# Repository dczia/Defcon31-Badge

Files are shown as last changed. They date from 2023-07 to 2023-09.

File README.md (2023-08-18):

# Defcon31-Badge
DCZia 2023 DC31 Badge - Electric Sampler

```
   ____  ___________   _          ________          __       _
   / __ \/ ____/__  /  (_)___ _   / ____/ /__  _____/ /______(_)____
  / / / / /      / /  / / __ `/  / __/ / / _ \/ ___/ __/ ___/ / ___/
 / /_/ / /___   / /__/ / /_/ /  / /___/ /  __/ /__/ /_/ /  / / /__
/_____/\____/  /____/_/\__,_/  /_____/_/\___/\___/\__/_/  /_/\___/

   _____                       __
  / ___/____ _____ ___  ____  / /__  _____
  \__ \/ __ `/ __ `__ \/ __ \/ / _ \/ ___/
 ___/ / /_/ / / / / / / /_/ / /  __/ /
/____/\__,_/_/ /_/ /_/ .___/_/\___/_/
                    /_/
```

## About
The DCZia Electric Sampler - A eurorack format drum machine, sampler, and step sequencer powered by
the Pi2040.

## Specs

RPI 2040 Microconroller
OLED Screen
3.5mm Audio Out Jack
3.5mm Midi In / Out (TRRS)
3.5mm Sync In / Out
MicroSD Card Slot
Eurorack Power Connector
Battery Power

## Build Guide

The badge comes with all surface mount components already assembled on the board. You will need to
solder on the keyswitches, audio jacks, screen, rotary encoders, and battery box.

First add the audio jacks. Install all the jacks and make sure they are flat and perpendicular with
the board. Next install the front board first aligning the jacks with the holes in the front board.
Then connect the bottom pin header to the front board. The header will be off by one, THIS IS OK for
the v1.1 board! Then carefully flip over the board and solder on the jacks.

Remove the front panel.

Then insert a keyswitch, or all keyswitches onto the board. Check that the metal pins are not bent,
and if so gently straignten them out with your fingers or a pair of tweezers. Carfully flip the
board over and solder on the keyswitches.

Next add the rotary encoders. Push them through the board, and you may need to gently fold in the
side stabilization pins if they do not line up correctly. Flip over the board and solder these in. 

Next with the board facing forward and on a flat surface, put the screen in. The legs of the screen
should not protrude through the back of the board past the holes, or only a tiny bit. You may need
to use something like a pencil or something to help the screen lay flat, standing off from the
board. Gently solder from the front to establish a mechanical connection to the board, then once the
screen is secure, flip over and solder the back. You must solder the back pads to endure a
connection from the screen to the microcrontroller. 

Finally flip the board over and gently attach the battery pack somewhere on the back with the
supplied double sticky tape. Then solder on the leads from the battery pack to the pads on the
bottom left side of the back of the board.

## User Manual

Currently the firmware is not complete, and the user interface may change.

The Select Knob will change between options on the screen, and push selects the currently
highlighted option.

The Volume knob will change the volume.

The PLAY button will play / pause any currently running program

There are a few modes on the v1 software.
A LED light mode.
A Sampler mode with a sequencer. You can load a wav file from the onboard flash, and then add a sequence and control the steps with the 8 key switches, and adjust per step volume.
A Sequencer mode which will play pre progarmed sequences. (Still under dev)
A Midi controller mode. You can adjust what notes / cc params are output via the python code in our repo.
A USB HID Device mode. The keys will output 0-9 and the device will emulate a keyboard.

## Notes

If you picked up a V1 board at Con, the board shipped with our testing firmware. Please flash the V1 firmware for more features.

Additional Features and changes will be coming soon!

## Updating the software / firmware

To update the software on the board you can do two things.

1. Use the fimware blob from our release section. To use this, unplug and turn off the module. Using something non conductivem press and hold the button on the RPI 2040 (The BootSelect Button) while powering on the unit via a micro usb cable. You should then see a mass storage drive appear on your computer. Drag the single uf2 file onto the drive. Then the unit should restart with the new firmware.

2. You can also plug the unit into your computer via the micro usb and drag the contents of the Production/Software folder onto the mass storage drive. The unit should reboot when complete. Sometimes if your computer transfers the files too slow this can cause issues with the RPI rebooting before all the software is complete.

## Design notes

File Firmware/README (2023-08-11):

To flash, hold down the BOOTSEL button on the Pi Pico and plug into a computer
Copy the DCZiaSampler.uf2 to the Pico
The Pico should automatically reboot with the full firmware

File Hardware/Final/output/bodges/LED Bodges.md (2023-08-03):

### Bodges required for 1.0 LED board

These bodges are required in order for a version 1.0 LED board (no version note on the board) to work with a 1.0 or 1.1 back board.  If you have a later version of the LED board, you will not need these changes and you will have to revert your backboard.

### The Issue

When designing the board to board connector, originally a 4 pin connector was used.  The master layout was created, and then forked into the front board and the back board.  Later, there was a desire to bring SDA/SCL to the front board for the SAO connector, so the board-to-board was updated to be a 5 pin.

However, on the front board the new pin was added to the bottom, and on the back board the new pin was added to the top, leaving us with a off-by-one error

### The Fix

To fix this, we will sever the I2C SDA/SCL lines, and move the power lines slightly.  You will need a sharp knife to cut the traces and also to remove some solder mask, some rosin flux solder, and a short piece of wire.

Start with the front board.  Locate the board to board connector at the lower left of the board.

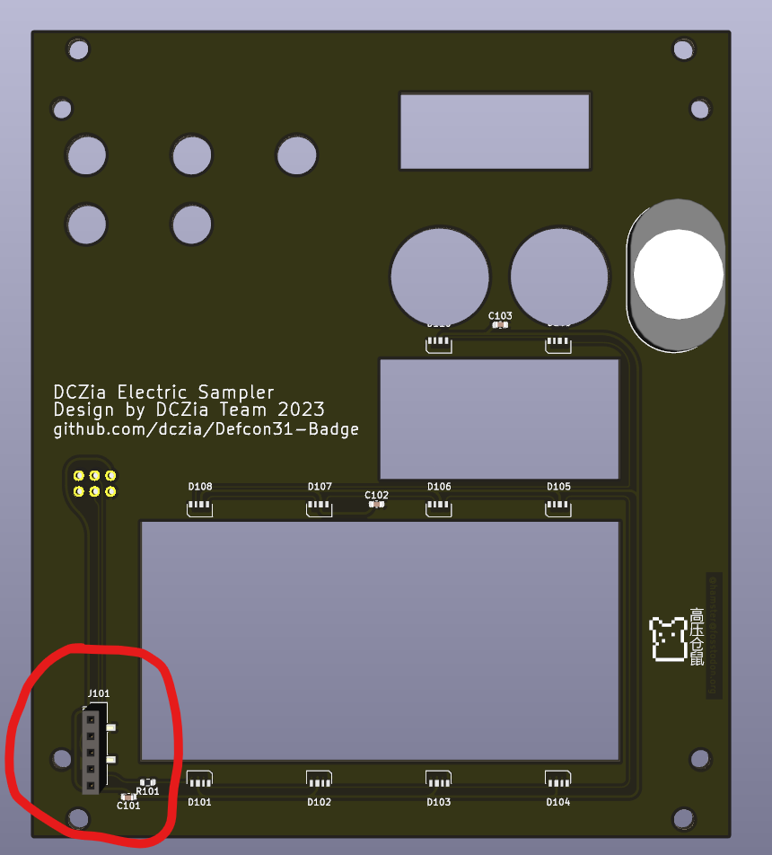
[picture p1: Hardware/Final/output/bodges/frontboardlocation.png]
front


1. Take your knife and sever the two I2C lines above the connector.  These are the thin ones to the right - ***DO NOT*** cut the thicker line to the left.  
2. Take a short piece of wire, and jumper pin 4 of the connector to the left terminal of R101.

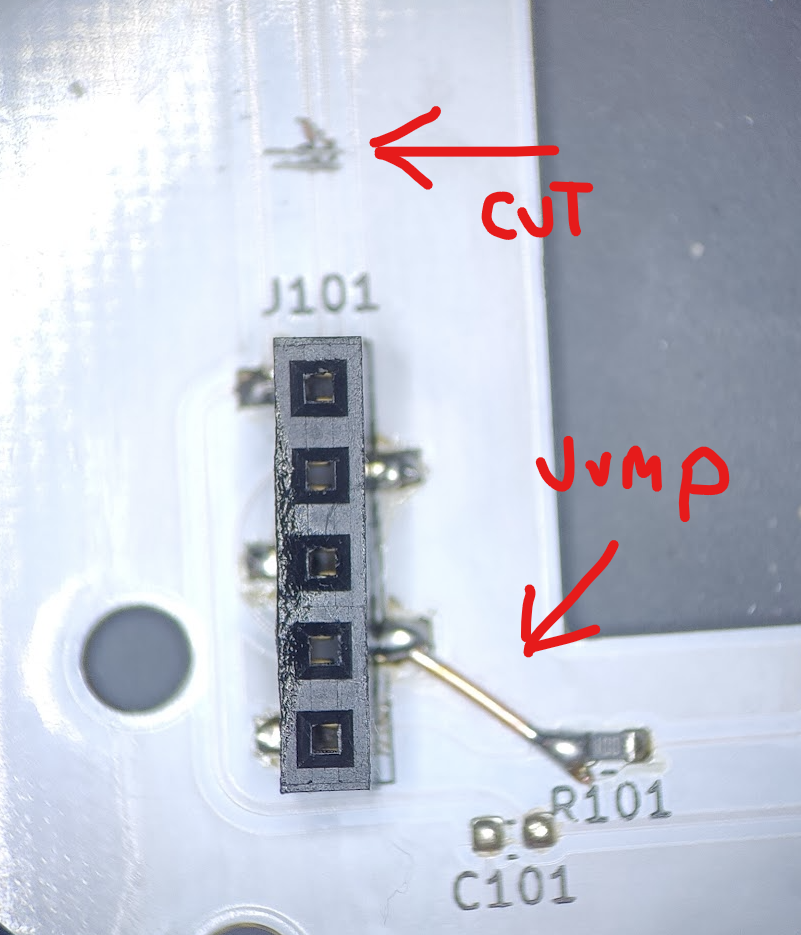
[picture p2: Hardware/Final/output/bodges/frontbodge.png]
frontbodge


Now we will move the back board.  Flip the board over to see the back side.  Locate the 5 pin connector in the lower left of the board.

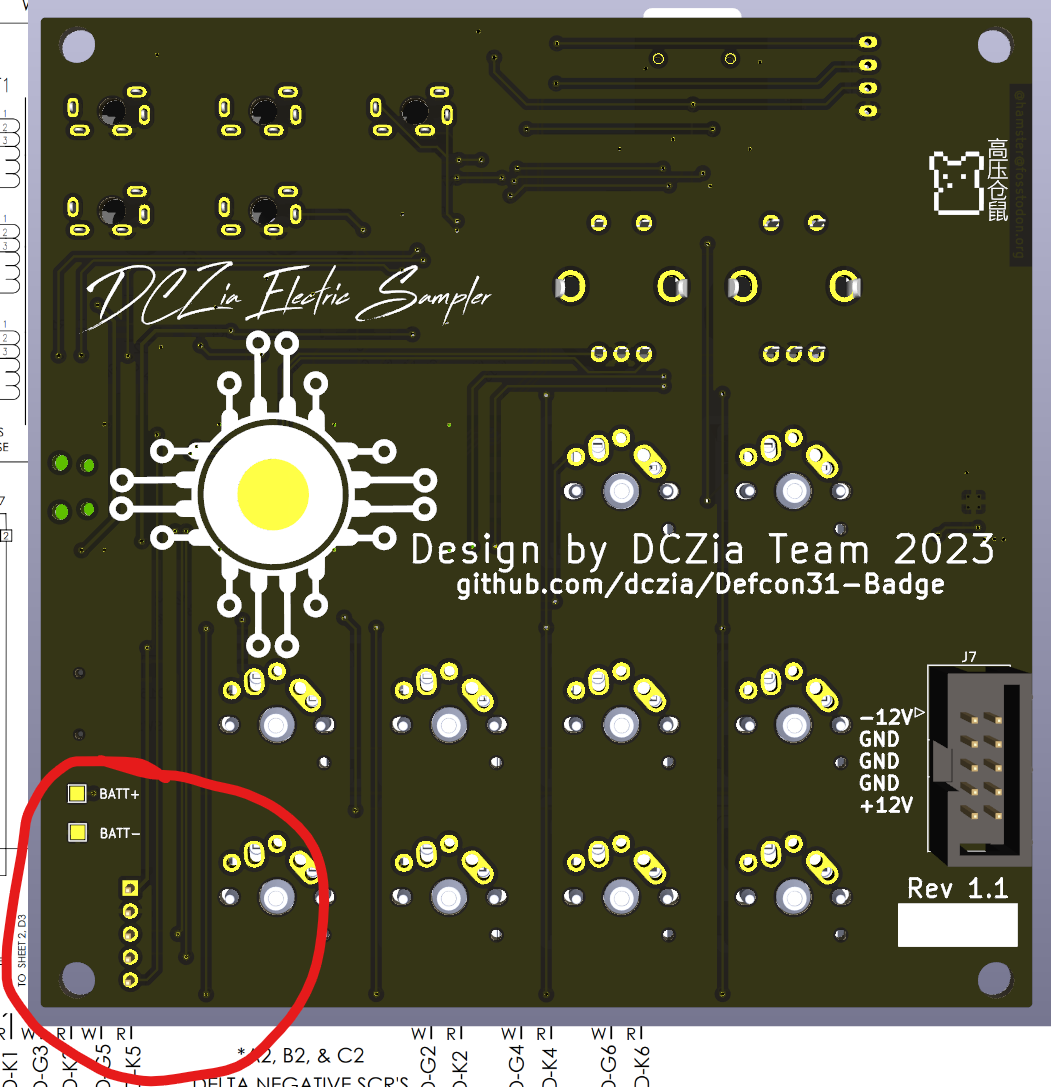
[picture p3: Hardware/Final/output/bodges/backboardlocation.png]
back


At this location, you will need to perform several actions.

1. Using solder, bridge the top two pins together.  Heat both, apply solder, and continue applying solder while pulling the iron away.
2. The second pin here is connected to the ground plane via a single trace.  Sever this trace.
3. At pin 3, scrape some of the solder mask off the ground plane next to it.  Using your solder, tin the exposed copper, and then using the technique from (1) bridge the ground plane with pin 3.
4. Locate the I2C lines to the right of the connector.  These are the small lines that both go into vias at the bottom.  Sever these lines with your knife.

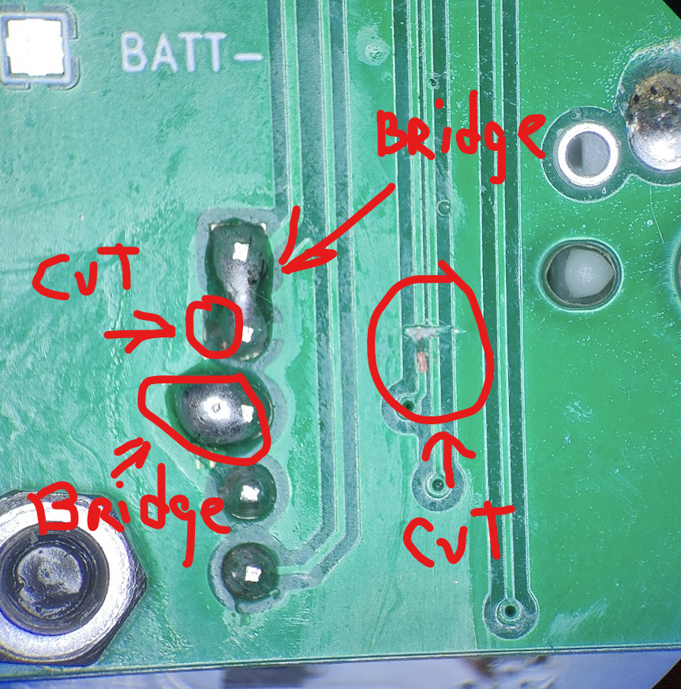
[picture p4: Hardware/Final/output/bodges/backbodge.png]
backbodge


At this point, the LEDs will now work.

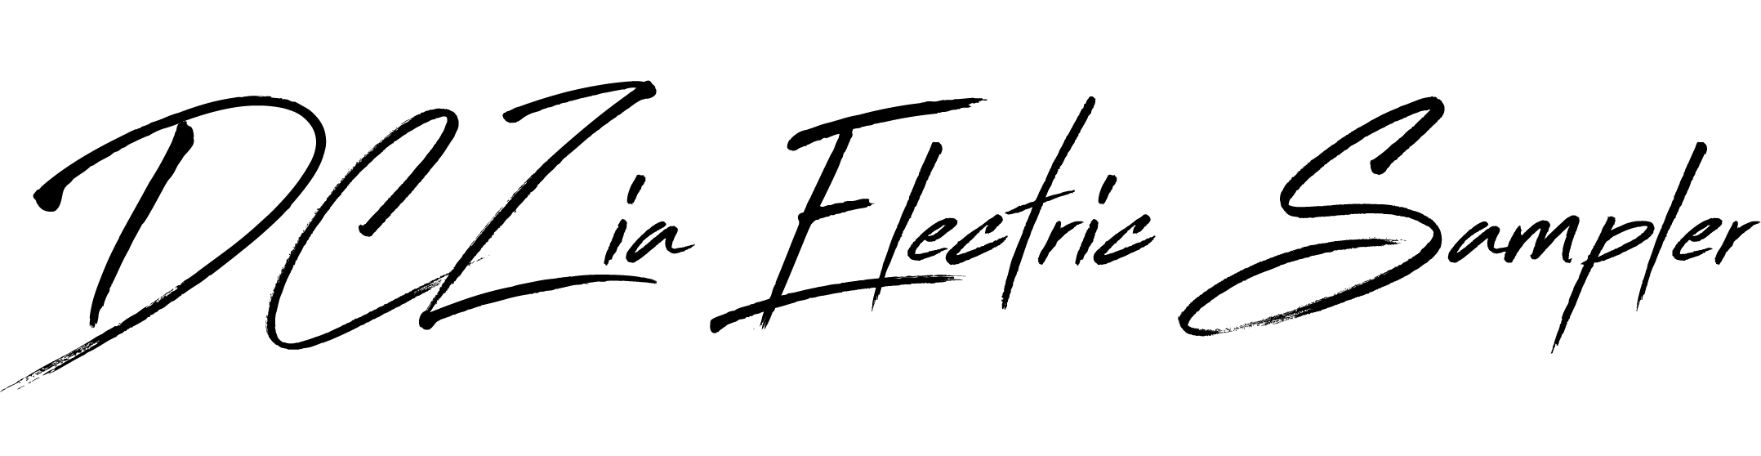
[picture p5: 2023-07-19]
Hardware/Final/images/DCZiaElectricSampler.png

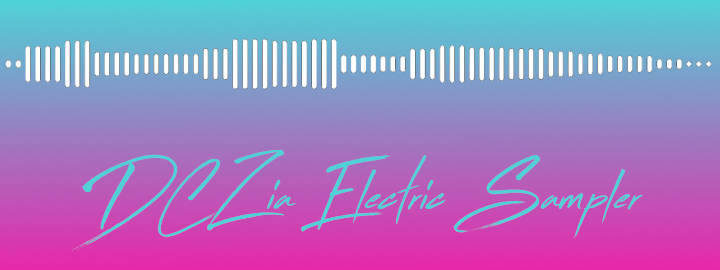
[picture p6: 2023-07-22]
Images/dc31-ziastickerlarge.png

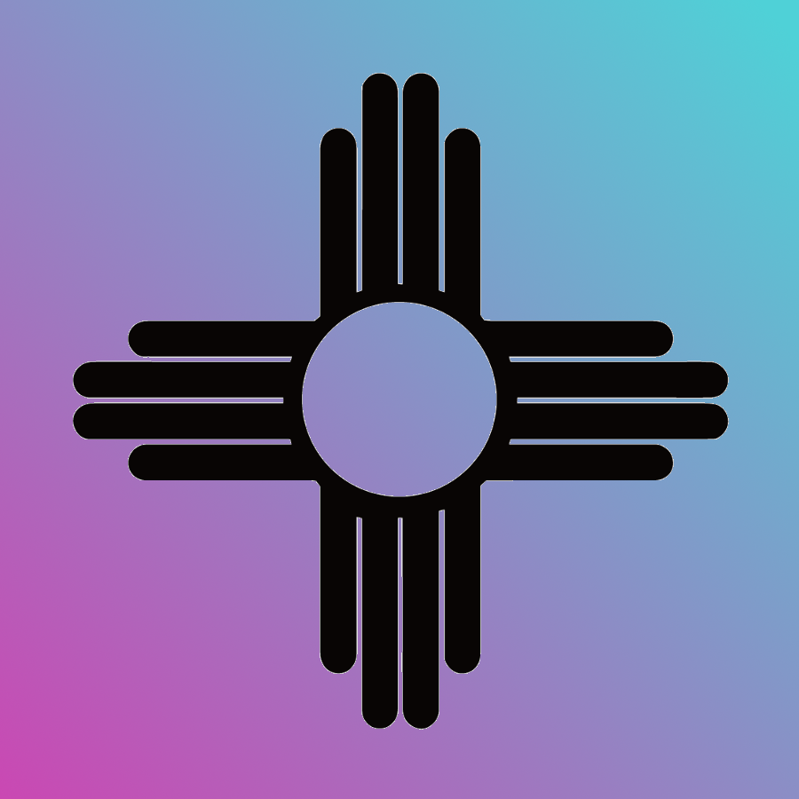
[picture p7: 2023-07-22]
Images/zialarge.png

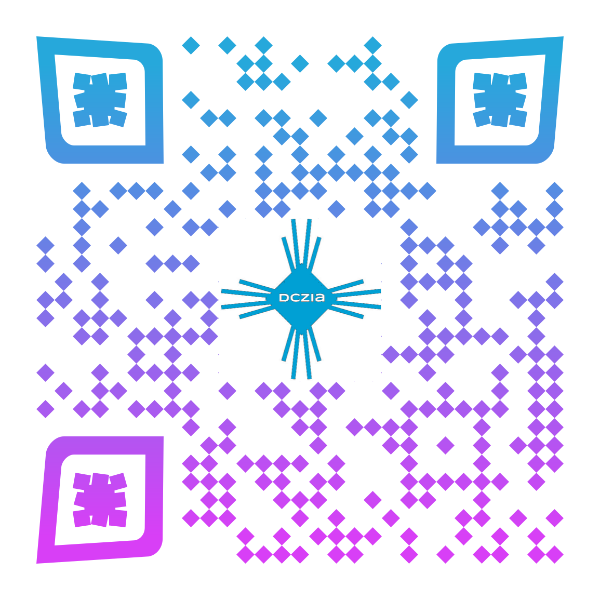
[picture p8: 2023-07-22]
Images/dczia_webpage_qr.png

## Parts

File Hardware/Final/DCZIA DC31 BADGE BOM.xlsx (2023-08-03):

Refdes | Description | Manufacturer | Part Number | Supplier | Supplier Part Num | Height | Package | Cost Each (assumes 100 unit pricing) | Qty per board | Cost per board | QOH | Needed | Run Cost $ | Ordered?
Virtual, Non-stuff |  |  |  |  |  |  |  |  |  |  |  |  | Run Units | 110
J7 | 2x5 IDC header
Stuff
J2,J4-6 (Rev 1.0) | 1/8 through hole jacks | Molex | 47257-0001 | Mouser | 538-47257-0001 (https://www.mouser.com/ProductDetail/538-47257-0001) |  |  | 0.982 | 5 | 4.91 | 0 | 550 | 540.1
J2,J4-6 (Rev 1.1) | 1/8 through hole jacks | KYCON | STX-3790-5N | Digikey | 2092-STX-3790-5N-ND |  |  | 1.52536 | 5 | 7.6268 | 0 | 550 | 838.948 | 550
U2 | Op Amp | TI | TL074HIDR | Mouser | 595-OPA341UA (https://www.mouser.com/ProductDetail/595-OPA341UA) | 1 |  | 2.06 | 1 | 2.06 | 0 | 110 | 226.6 | 110
U5 | Optocoupler | Toshiba | 757-TLP2361TPRE | Mouser | 757-TLP2361TPRE (https://www.mouser.com/ProductDetail/757-TLP2361TPRE) |  |  | 0.477 | 1 | 0.477 | 0 | 110 | 52.47 | 110
U4 | Hex inverter | TI | SN74HCS04BQAR | Mouser | 595-SN74HCS04PWR (https://www.mouser.com/ProductDetail/595-SN74HCS04PWR) | 1 |  | 0.18 | 1 | 0.18 | 100 | 10 | 1.8 | 10
U1 | Pi Pico | Raspberry Pi | SC0918 | Mouser | 358-SC0918 |  |  | 6 | 1 | 6 | 0 | 110 | 660 | 110
U3 | I2S Audio Amp | Analog | MAX98357AETE+T | Mouser | 700-MAX98357AETE+T (https://www.mouser.com/ProductDetail/700-MAX98357AETE%2bT) | 1 |  | 2.11 | 1 | 2.11 | 0 | 110 | 232.1 | 110
U6 | 5V v-reg | IT | TPS62153RGTR | Mouser | 595-TPS62153RGTR | 1 |  | 1.03 | 1 | 1.03 | 0 | 110 | 113.3 | 110
J9 | SD Card socket | Aliexpress | https://www.aliexpress.us/item/2251801691891544.html |  |  |  |  | 0.08 | 1 | 0.08 | 110 | 0 | 0
D100-D110 | Neopixels, side fire | Aliexpress | https://www.aliexpress.us/item/2261799823015387.html |  |  |  |  | 0.05 | 10 | 0.5 | 1500 | 0 | 0
 | Speaker, 8 ohm panel mount | Aliexpress | https://www.aliexpress.us/item/2251832791435459.html |  |  |  |  | 0.6 | 1 | 0.6 | 110 | 0 | 0
 | OLED | Aliexpress | https://www.aliexpress.us/item/3256804436278763.html |  |  |  |  | 1.85 | 1 | 1.85 | 110 | 0 | 0
D1-16 | Schottky diodes |  | NSR0320MW2T3G | Mouser | 863-NSR0320MW2T3G | 0.9 | SOD-323 | 0.127 | 16 | 2.032 | 0 | 1760 | 223.52 | 2500
C1,C4-6 | 0.1uF |  | 0603YC104KAT4A | Mouser | 581-0603YC104K (https://www.mouser.com/ProductDetail/581-0603YC104K) | 0.9 | 0603 | 0.011 | 4 | 0.044 | 1000 | 0 | 0
C2 | 10uF |  | CL21A106KOQNNNF | Mouser | 187-CL21A106KOQNNNF | 1.45 | 0805 | 0.034 | 1 | 0.034 | 0 | 110 | 3.74 | 125
C3 | 3.3nF |  | 885012207036 | Mouser | 710-885012207036 | 1.45 | 0805 | 0.035 | 1 | 0.035 | 0 | 110 | 3.85 | 125
C7 | 22uF |  | CL21A226MQQNNNE | Mouser | 187-CL21A226MQQNNNE | 1.45 | 0805 | 0.031 | 1 | 0.031 | 0 | 110 | 3.41 | 125
L1 | 2.2uH inductor |  | NRS3015T2R2MNGH | Mouser | 963-NRS3015T2R2MNGH |  | 3015 | 0.167 | 1 | 0.167 | 0 | 110 | 18.37 | 125
Q1 | 3904 NPN |  | MMBT3904-TP | Mouser | 833-MMBT3904-TP | 1 | SOT-23 | 0.048 | 1 | 0.048 | 100 | 10 | 0.48 | 125
R1,R4 | 1k |  | 0603WAF1001T5E | Mouser | 303-0603WAF1001T5E (https://www.mouser.com/ProductDetail/303-0603WAF1001T5E) | 0.45 | 0603 | 0.001 | 2 | 0.002 | 5000 | 0 | 0
R2 | 220k |  | RMC1/16-224JTP | Mouser | 791-RMC1/16-224JTP (https://www.mouser.com/ProductDetail/791-RMC1-16-224JTP) | 0.45 | 0603 | 0.001 | 1 | 0.001 | 5000 | 0 | 0
R3,R5,R11 | 100k |  | WR06X104 JTL | Mouser | 791-WR06X104JTL (https://www.mouser.com/ProductDetail/791-WR06X104JTL) | 0.45 | 0603 | 0.001 | 3 | 0.003 | 5000 | 0 | 0
R6 | 10k |  | 0603WAJ0103T5E | Mouser | 303-0603WAJ0103T5E | 0.45 | 0603 | 0.001 | 1 | 0.001 | 5000 | 0 | 0
R7 | 1M |  | 0603WAF1004T5E | Mouser | 303-0603WAF1004T5E (https://www.mouser.com/ProductDetail/303-0603WAF1004T5E) | 0.45 | 0603 | 0.001 | 1 | 0.001 | 5000 | 0 | 0
R8 | 10R |  | 0603WAJ0100T5E | Mouser | 303-0603WAJ0100T5E | 0.45 | 0603 | 0.001 | 1 | 0.001 | 0 | 110 | 0.11 | 5000
R9 | 33R |  | 0603WAJ0330T5E | Mouser | 303-0603WAJ0330T5E | 0.45 | 0603 | 0.001 | 1 | 0.001 | 0 | 110 | 0.11 | 5000
R10 | 220R |  |  |  |  | 0.45 | 0603 | 0.001 | 1 | 0.001 | 5000 | 0 | 0
SW1-10 | CherryMX switches |  |  |  |  |  |  | 0.27 | 10 | 2.7 | 1300 | 0 | 0
SW11-12 | Rotary Encoder |  | PEC12R-4115F-S0012 | Mouser | 652-PEC12R-4115F-S12 |  |  | 1.1 | 2 | 2.2 | 0 | 220 | 242 | 125
SW13 | SPST |  | JS102011SAQN | Mouser | 611-JS102011SAQN |  |  | 0.534 | 1 | 0.534 | 0 | 110 | 58.74 | 125
 |  |  |  |  |  |  |  |  |  | 0
Other Parts |  |  |  |  |  |  |  |  |  | 0
 | Boxes | Bob |  |  |  |  |  | 1 | 1 | 1
 | Lanyards | Litho |  |  |  |  |  | 2 | 1 | 2
 | Batteries | hamster |  |  |  |  |  | 0.31 | 3 | 0.93
 | Battery Boxes | hamster |  |  |  |  |  | 0.45 | 1 | 0.45
 | Knobs | hamster |  |  |  |  |  | 0.5 | 2 | 1
 | Key caps | hamster |  |  |  |  |  | 0.25 | 10 | 2.5
 | PCBs | hamster |  |  |  |  |  | 4 | 2 | 8
 | Bolts | to-order |  |  |  |  |  | 8 | 0.1 | 0.8
 | Double sided tape | to-order |  |  |  |  |  | 0.25 | 1 | 0.25
 |  |  |  |  |  |  |  |  |  | 0
 | Contributions
 | bob | 2500 |  |  |  |  | Total Per Badge | 52.1898
 | litho | 1100 |  |  |  |  | Total for Run | 2679.548

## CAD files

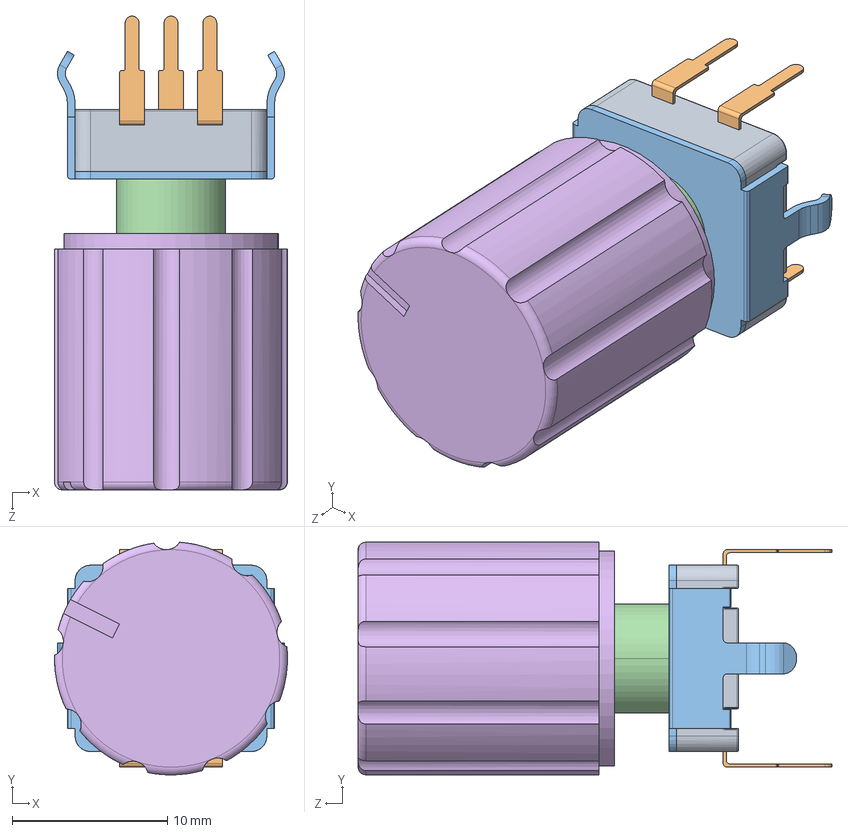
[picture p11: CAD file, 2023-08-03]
Hardware/Final/3d/RotaryEncoder.SLDASM
15.0 x 15.0 x 30.5 mm
12mm Incremental Encoder Base.stp.STEP
12mm Incremental Encoder Pin.stp.STEP x 5
12mm Incremental Encoder Anti-Rotation Plate.stp.STEP
12mm Incremental Encoder Threaded Tube.stp.STEP
12mm Incremental Encoder Shaft.stp.STEP
Knob

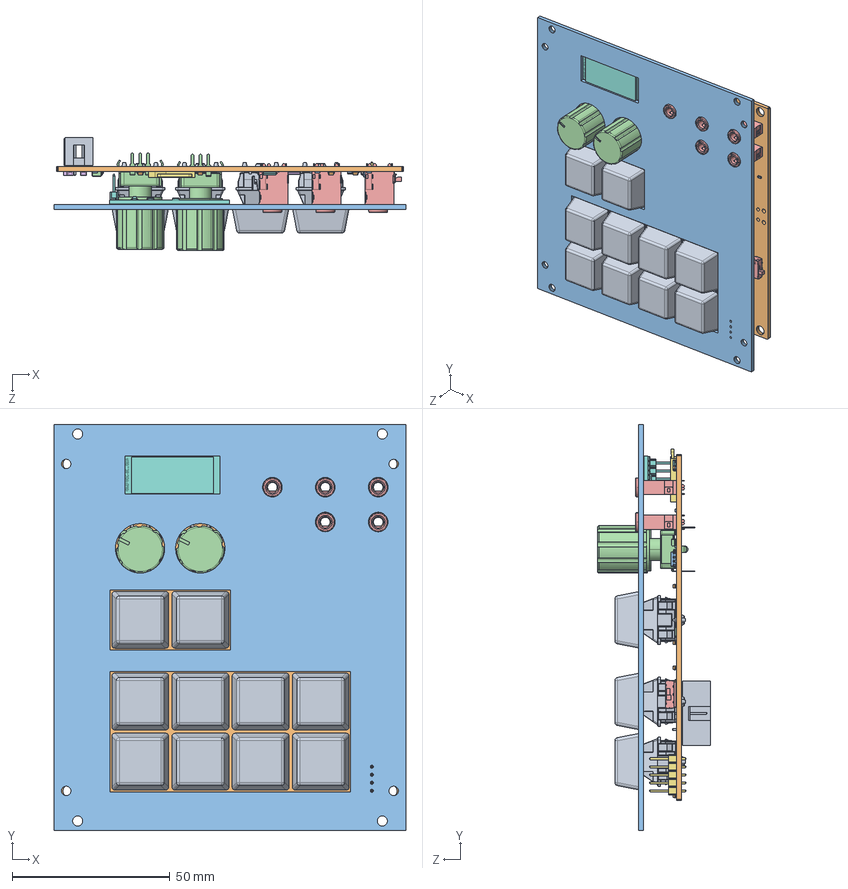
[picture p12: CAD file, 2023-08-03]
Hardware/Final/3d/dc31-badge.SLDASM
111.4 x 128.5 x 35.8 mm
COMPOUND.step x 10
SOLID.step x 16
SOLID-0.step x 11
COMPOUND-1.step x 2
SOLID-2.step x 5
SOLID-3.step x 3
SOLID-4.step
SOLID-5.step
SOLID-6.step x 4
SOLID-7.step
SOLID-8.step
SOLID-9.step
SOLID-10.step
SOLID-11.step
SOLID-12.step
COMPOUND-13.step
SOLID-14.step
dc31 PCB.step
dc31-front PCB.step

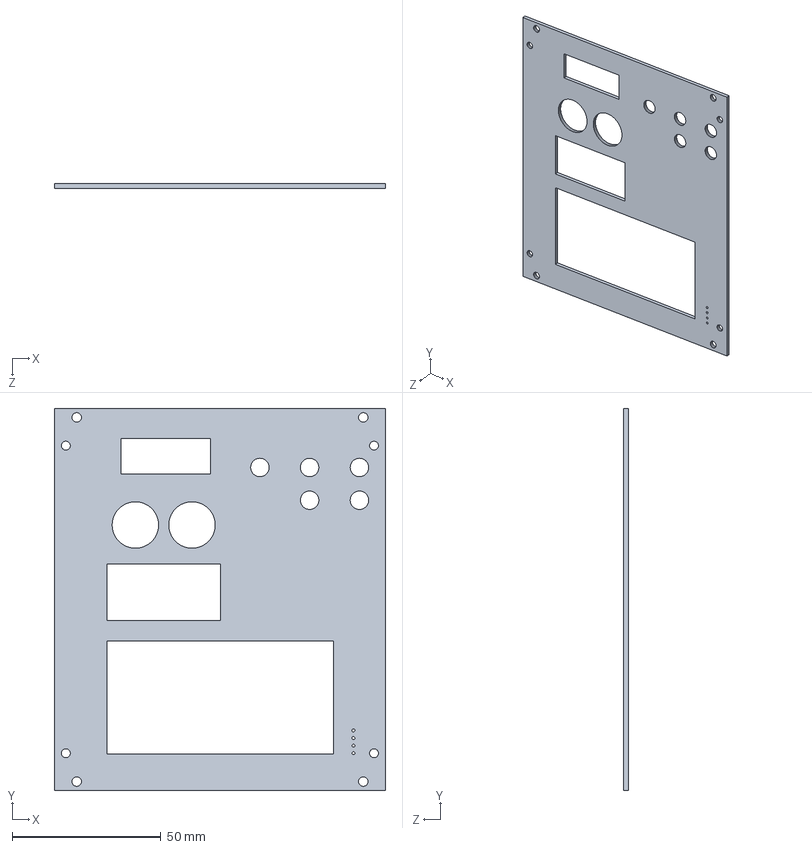
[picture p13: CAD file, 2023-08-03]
Hardware/Final/3d/dc31-front2.step.SLDASM
111.4 x 128.5 x 1.58 mm

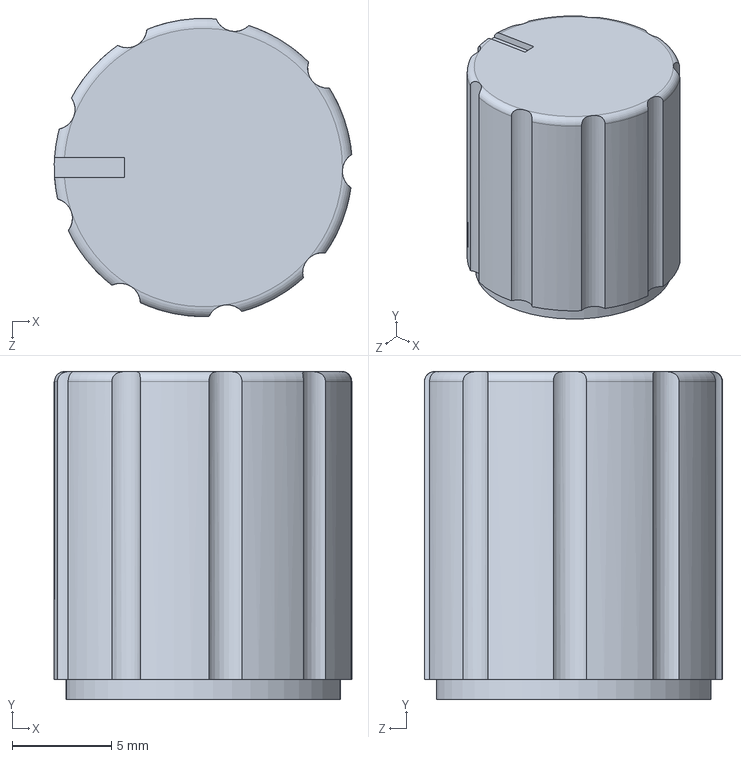
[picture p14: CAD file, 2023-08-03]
Hardware/Final/3d/Knob.SLDPRT
15.0 x 16.5 x 15.0 mm

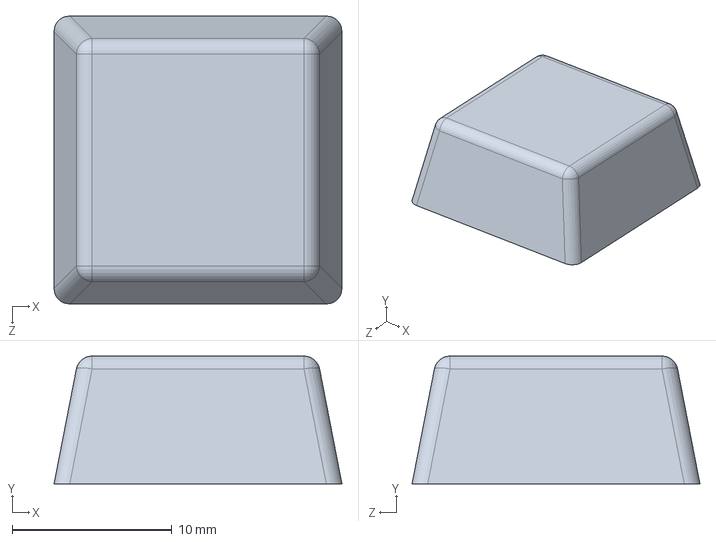
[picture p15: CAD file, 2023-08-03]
Hardware/Final/3d/Flat Keycap.SLDPRT
18.0 x 8.00 x 18.0 mm

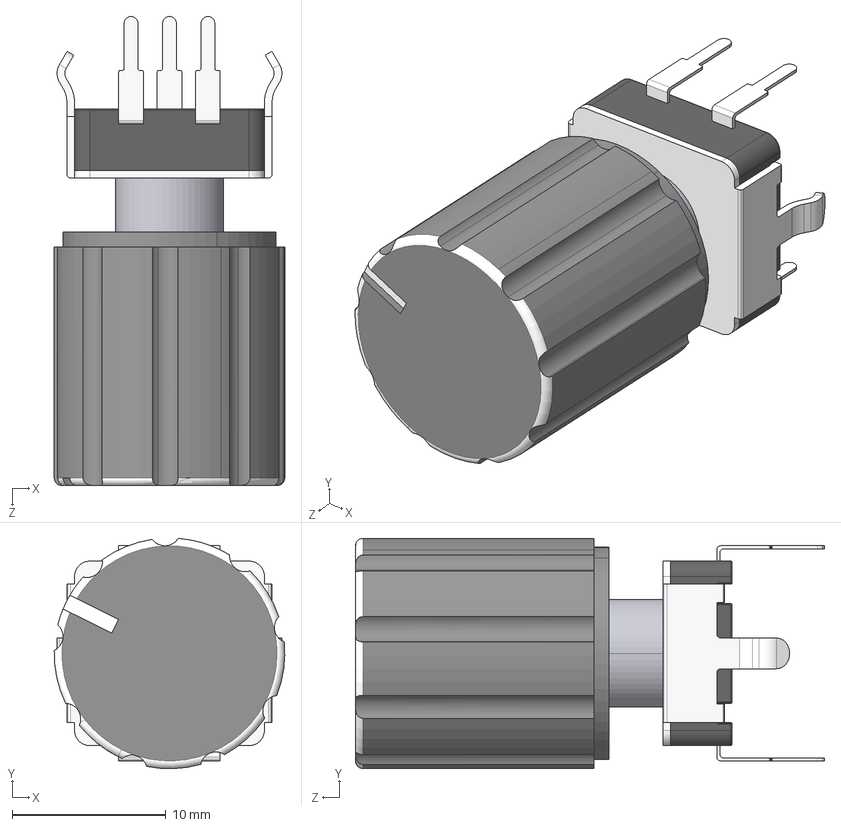
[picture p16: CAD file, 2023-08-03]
Hardware/Final/3d/Rotary_Encoder_With_Black_Knob.STEP
15.0 x 15.0 x 30.5 mm
12mm Incremental Encoder Base.stp.STEP
12mm Incremental Encoder Pin.stp.STEP x 5
12mm Incremental Encoder Anti-Rotation Plate.stp.STEP
12mm Incremental Encoder Threaded Tube.stp.STEP
12mm Incremental Encoder Shaft.stp.STEP
Knob

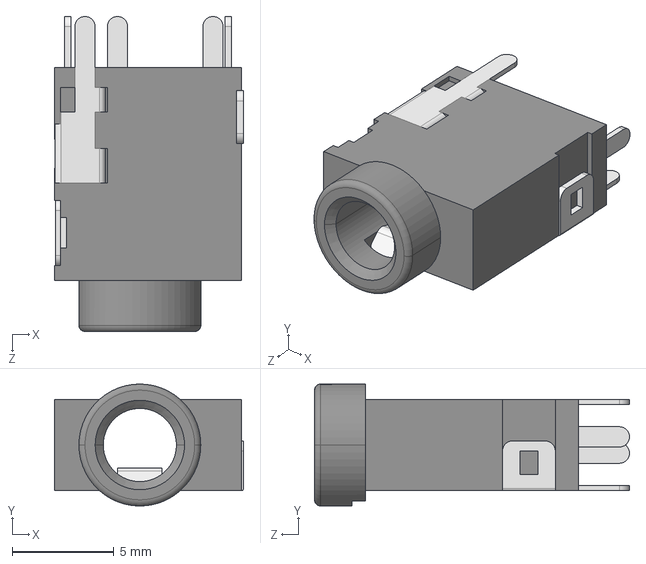
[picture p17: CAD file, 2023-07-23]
Hardware/Final/3d/STX-3790-5N_rA5.STEP
9.30 x 6.00 x 15.5 mm

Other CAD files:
Hardware/Final/3d/OLED 128x32 Display.step.SLDASM
Hardware/Final/3d/MicroSD.step.SLDASM
Hardware/Final/dc31-front2.step
Hardware/Final/3d/12mm Incremental Encoder Cap.stp.SLDPRT
Hardware/Final/3d/COMPOUND-3.step.SLDPRT
Hardware/Final/3d/COMPOUND-0.step.SLDPRT
Hardware/Final/3d/Rotary_Encoder_With_Knob.STEP
Hardware/Final/3d/dc31 PCB.step.SLDPRT
Hardware/Final/3d/COMPOUND.step.SLDPRT
Hardware/Final/3d/MX _ ___2.sldprt
Hardware/Final/3d/MX_ __LED.sldprt
Hardware/Final/3d/12mm Incremental Encoder - BOURNS PEC11S - No Knob.STEP
Hardware/Final/3d/12mm Incremental Encoder - BOURNS PEC11S.stp
Hardware/Final/3d/12mm Incremental Encoder Washer.stp.SLDPRT
Hardware/Final/3d/47257-0001.step
Hardware/Final/3d/Cherry MX Keycap.SLDPRT
Hardware/Final/3d/JS102011SAQN.SLDPRT
Hardware/Final/3d/JS102011SAQN.step.SLDASM
Hardware/Final/3d/JS102011SAQN.stp
Hardware/Final/3d/MX _ __.sldprt
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

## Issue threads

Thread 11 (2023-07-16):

Write sample playback code

catblade, 2023-07-16:
Single track sample playback code included
Need to expand to multi-track, lots of room for further improvements

skafreak, 2023-07-22:
Initial cut at multi-track playback in d1638a354413455145ad3647552e8981bc5a7c6d
Ongoing improvements:
Issue reading files from SD card, need to determine if this can be fixed in code or if there is a read speed limitation
Need user input for programming new sequences
Possible issue with not all tracks playing on first step (need to investigate further)
Add stepping LEDs to show current step
General improvements to UX (increase responsiveness, start time, etc.)

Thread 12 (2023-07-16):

Write Button handling code

catblade, 2023-07-16:
All prototype buttons functional, minimal code for actually controlling flow complete
Library includes matrix inputs for final product

Ancient123, 2023-07-26:
Button using examples are in. USB-HID provides a useful basic example thats pretty performant.
Will need some updates when the final hardware is in tho.

Closed 2023-07-26.

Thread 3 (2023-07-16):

Improve Input Control Flow Between States

catblade, 2023-07-16:

Ancient123, 2023-07-26:
Lots more examples of making clean entries and exits in this coding style. I generally like it so far.

skafreak, 2023-08-09:
Flow seems to be acceptable, closing unless future issues are identified.

Closed 2023-08-09.

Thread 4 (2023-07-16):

Write Sequencer Code

catblade, 2023-07-16:

catblade, 2023-07-16:
Ideally editable from device, and can be used to load sequence into sampler mode or MIDI sequencer mode

skafreak, 2023-08-09:
Core MIDI sequence code complete, not yet editable on from the badge menus.

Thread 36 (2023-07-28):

Badge Build Debug Validation checks

rlucero, 2023-07-28:
Hardware tests needed:

blinking LEDs, red, green, blue
All buttons are detected (10 key switches + 2 rotary encoder buttons)
Encoders working
OLED screen working
Audio working
SD card working
I don't really have a good way to verify sync in/out and midi in/out in a quick way, so I'm going to ignore those

Ideally the badge boots up, two lines on the screen, top line is a link to the github, bottom is status.  LEDS cycle solid colors, red/green/blue.  Pressing a button is obvious either on the screen or highlighting with LED.  Pressing encoder shows on screen.  Rotating encoder shows on screen and/or plays another sample to test the audio path.  Boot up shows whether a SD card was detected but assume the SD card is blank.

I just want to drop this on the badge as they come out of the oven to A/B test them as rework needed or ready to ship
@skafreak / @catblade / @Ancient123 is there a way we can stitch a debug check?

catblade, 2023-07-28:
Will look at it this weekend.  We have 2 encoder knobs.  What's the plan for the code there?  We'll want it easy for one of us to change it so we can test both?

skafreak, 2023-08-09:
I believe this was provided, but reopen if we need improvements

Closed 2023-08-09.

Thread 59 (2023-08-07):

Boot fails if no samples on SD Card / SD Missing / Other SD Error

lithochasm, 2023-08-07:
My production v1 badge fails to run. First I did not have any samples on the SD card, but after putting them in the samples directory, there is still no output. Maybe my SD is bad? Files written to card from my mac, plays fine on other computers, but is not seen on the badge.

main.py output:
Traceback (most recent call last):
  File "main.py", line 61, in <module>
  File "SequencerState.py", line 154, in __init__
OSError: [Errno 2] No such file/directory

skafreak, 2023-08-09:
This shouldn't have been happening. Are you using the code in the production folder? There should be error handling that spits out a message but then continues (tested on production v1.1 board).

lithochasm, 2023-08-09:
Looks like it was actually looking for samples in the flash of the pi. The sample folder is not in the prod folder so if you dont copy that over, it throws an error.

Closed 2023-08-09.

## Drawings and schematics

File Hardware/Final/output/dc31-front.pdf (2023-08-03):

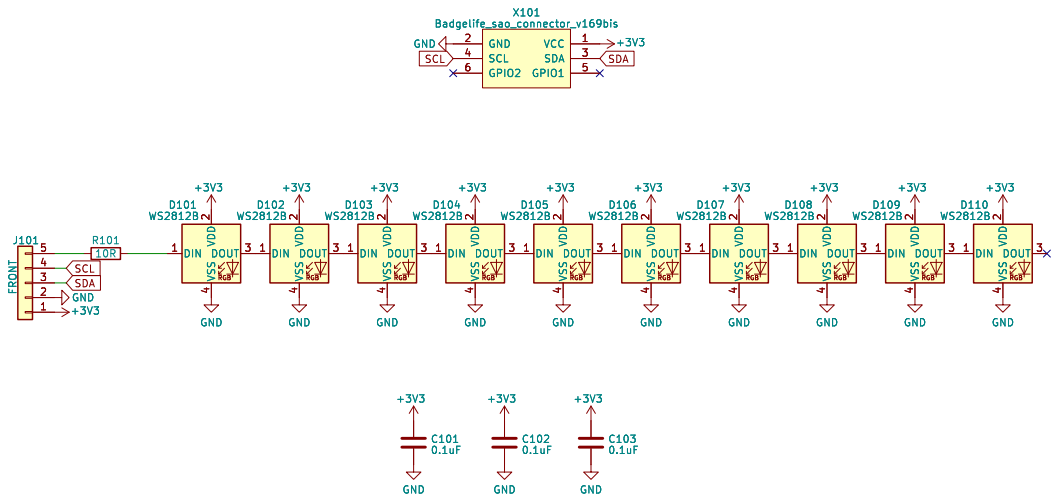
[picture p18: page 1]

Id: 1/1 Title: DCZia Electric Sampler File: dc31-front.kicad_sch Sheet: / DCZia

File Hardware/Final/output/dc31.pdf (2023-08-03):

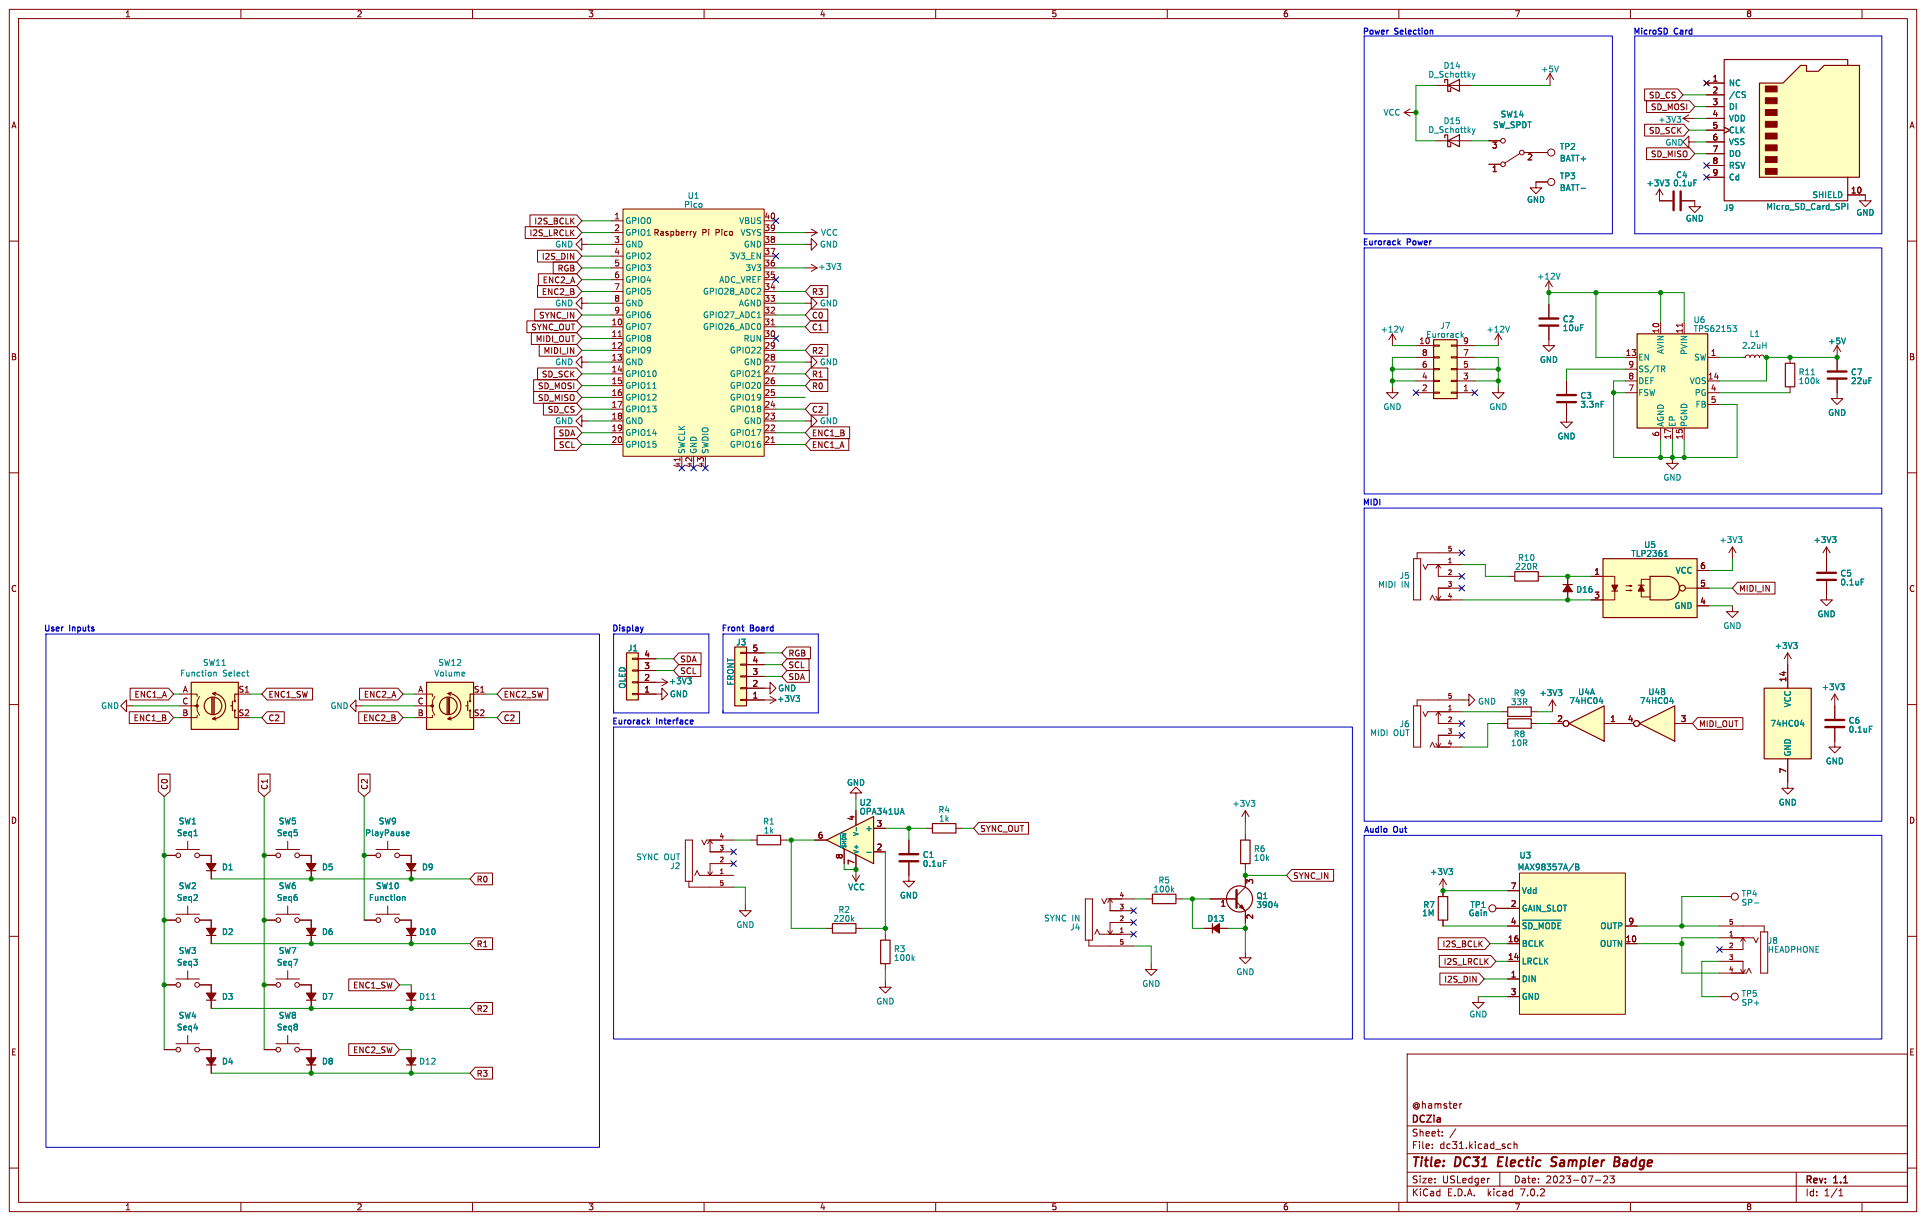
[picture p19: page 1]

Eurorack Power Power Selection

File: dc31.kicad_sch Sheet: / DCZia @hamster GND

Id: 1/1 Title: DC31 Electic Sampler Badge

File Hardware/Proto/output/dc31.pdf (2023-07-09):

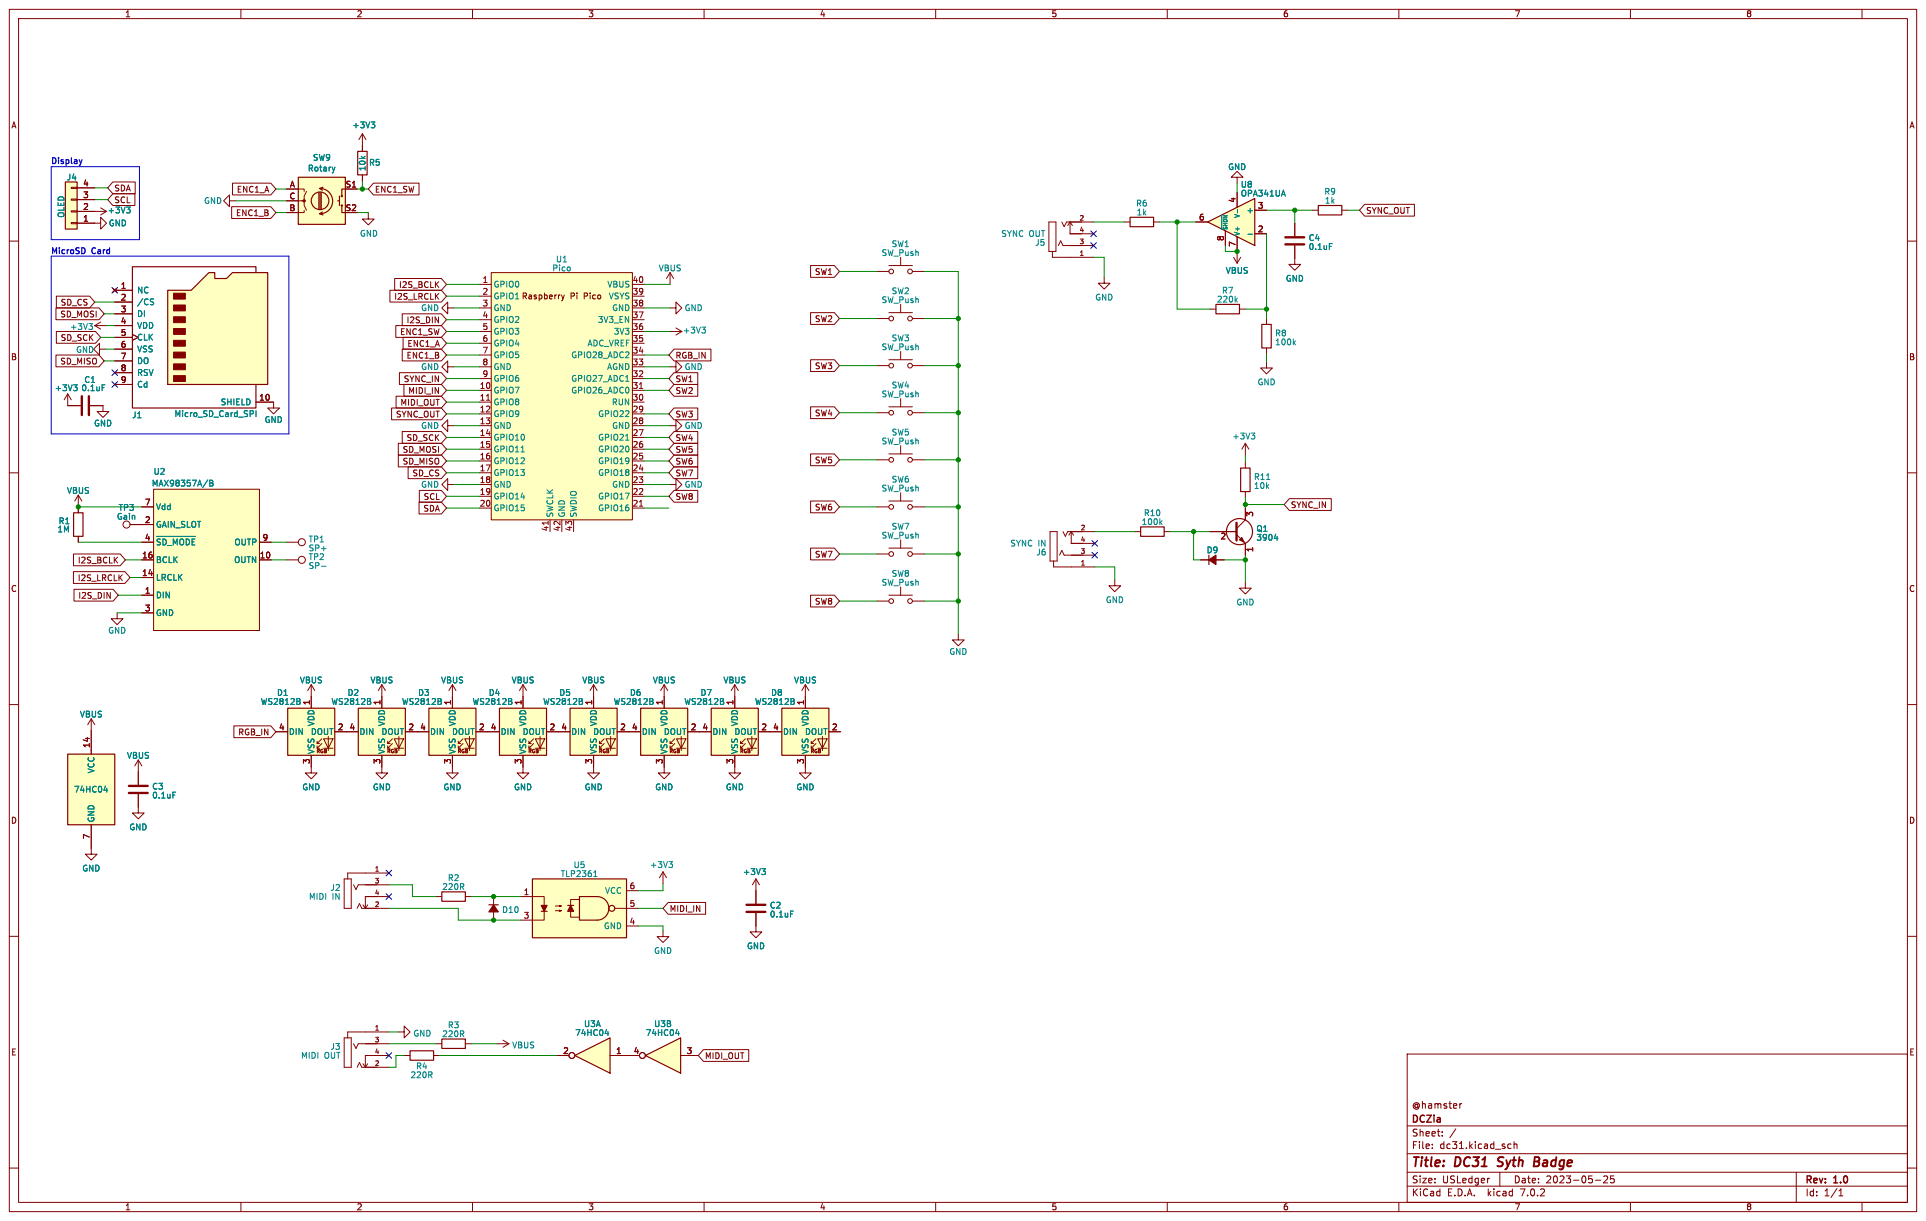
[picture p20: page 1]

3 DIN 4 VBUS VBUS D2 WS2812B VDD
RGB VDD

4 J2 MIDI IN VCC 14 GND

File: dc31.kicad_sch Sheet: / DCZia @hamster

Id: 1/1 Title: DC31 Syth Badge

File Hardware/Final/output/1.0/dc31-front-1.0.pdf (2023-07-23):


Id: 1/1 Title: DCZia Electric Sampler File: dc31-front.kicad_sch Sheet: / DCZia

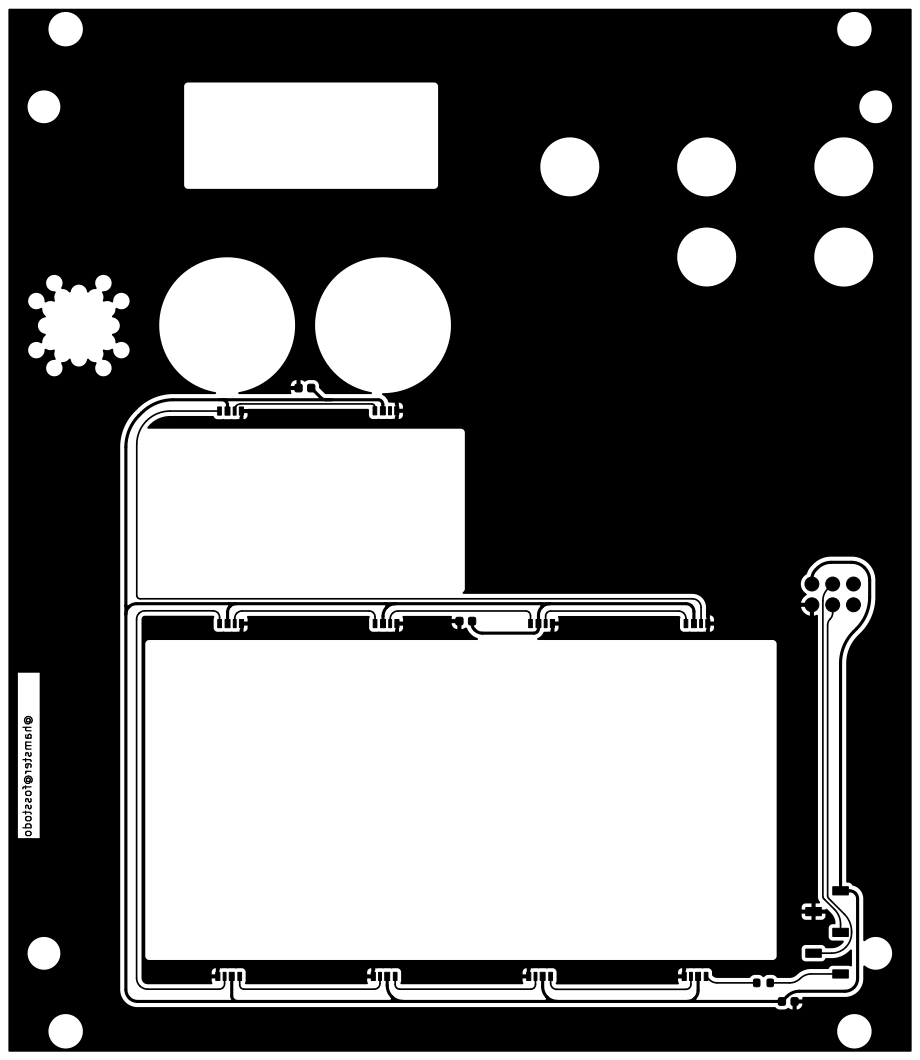
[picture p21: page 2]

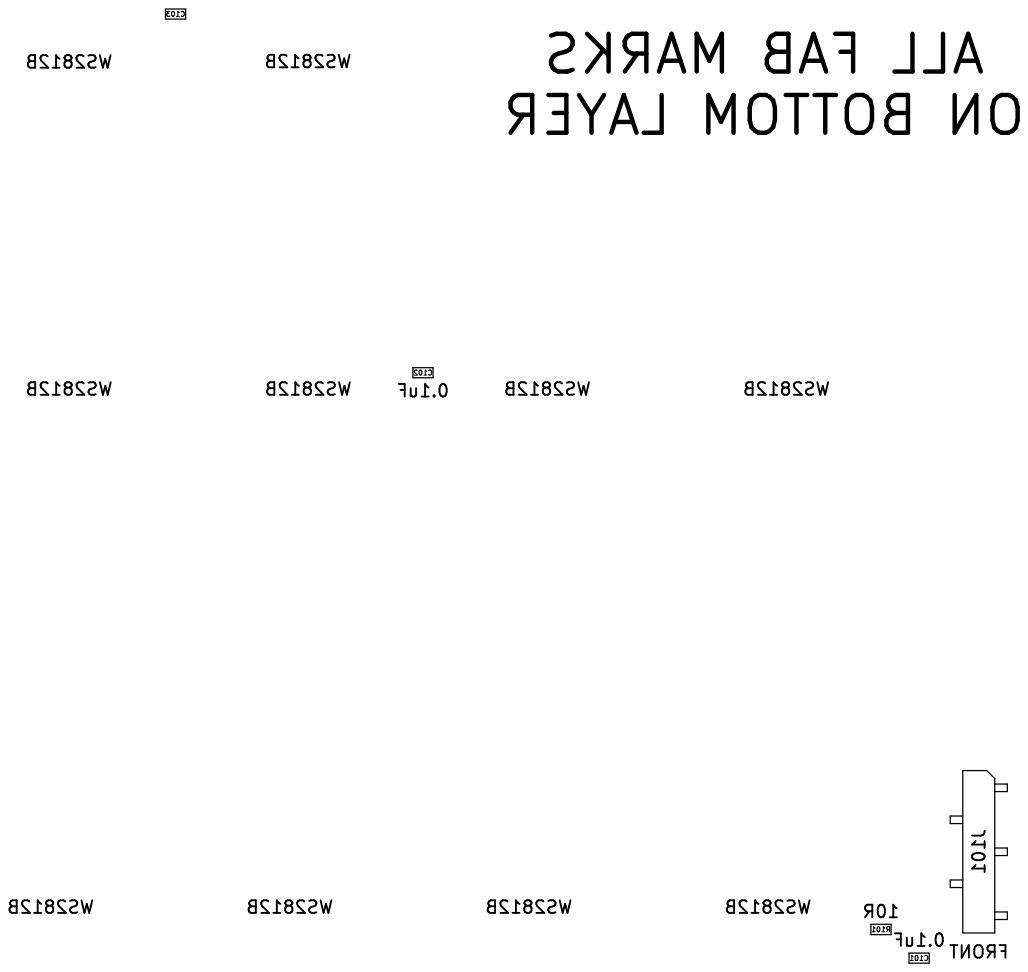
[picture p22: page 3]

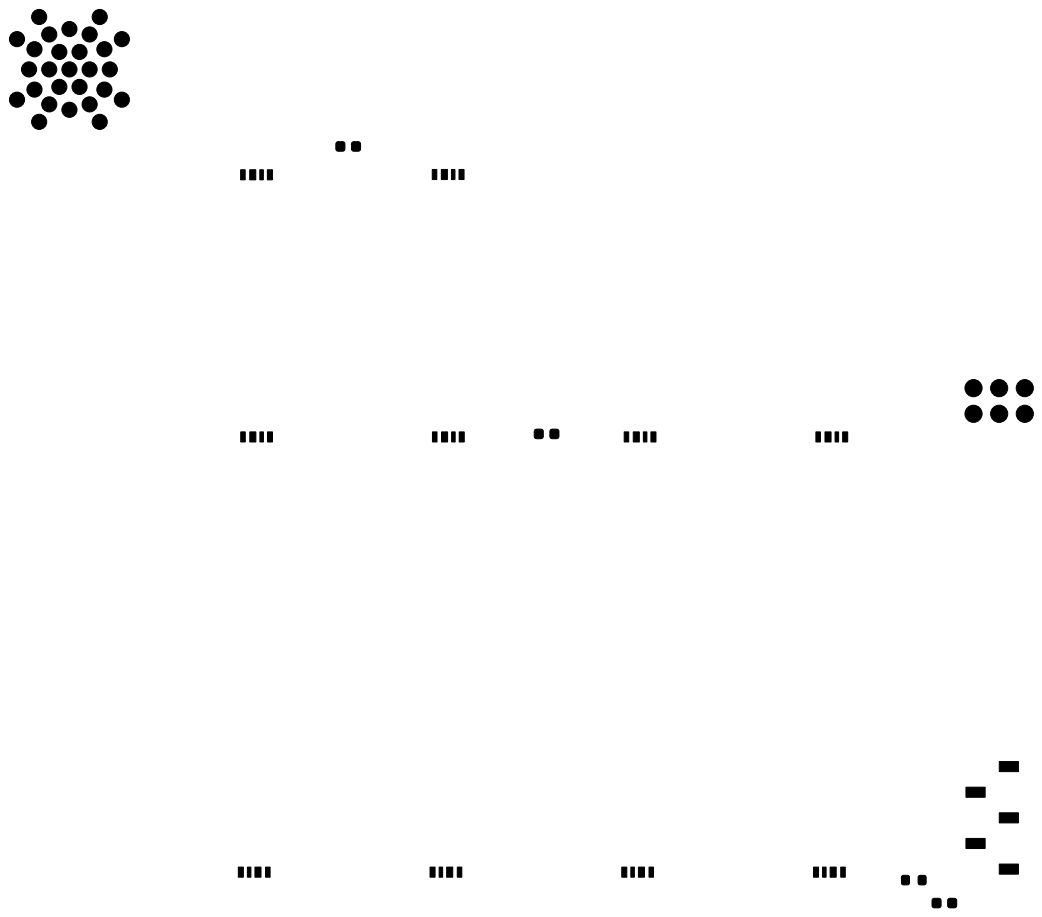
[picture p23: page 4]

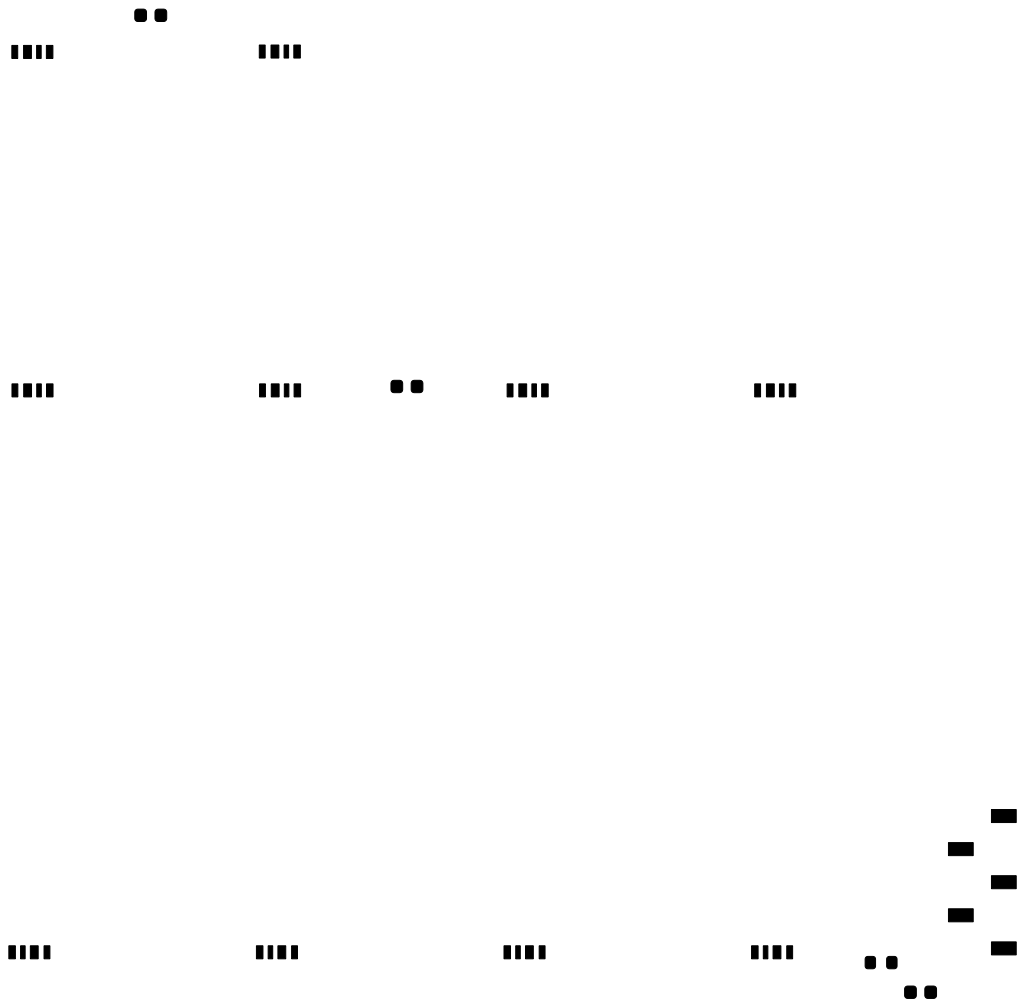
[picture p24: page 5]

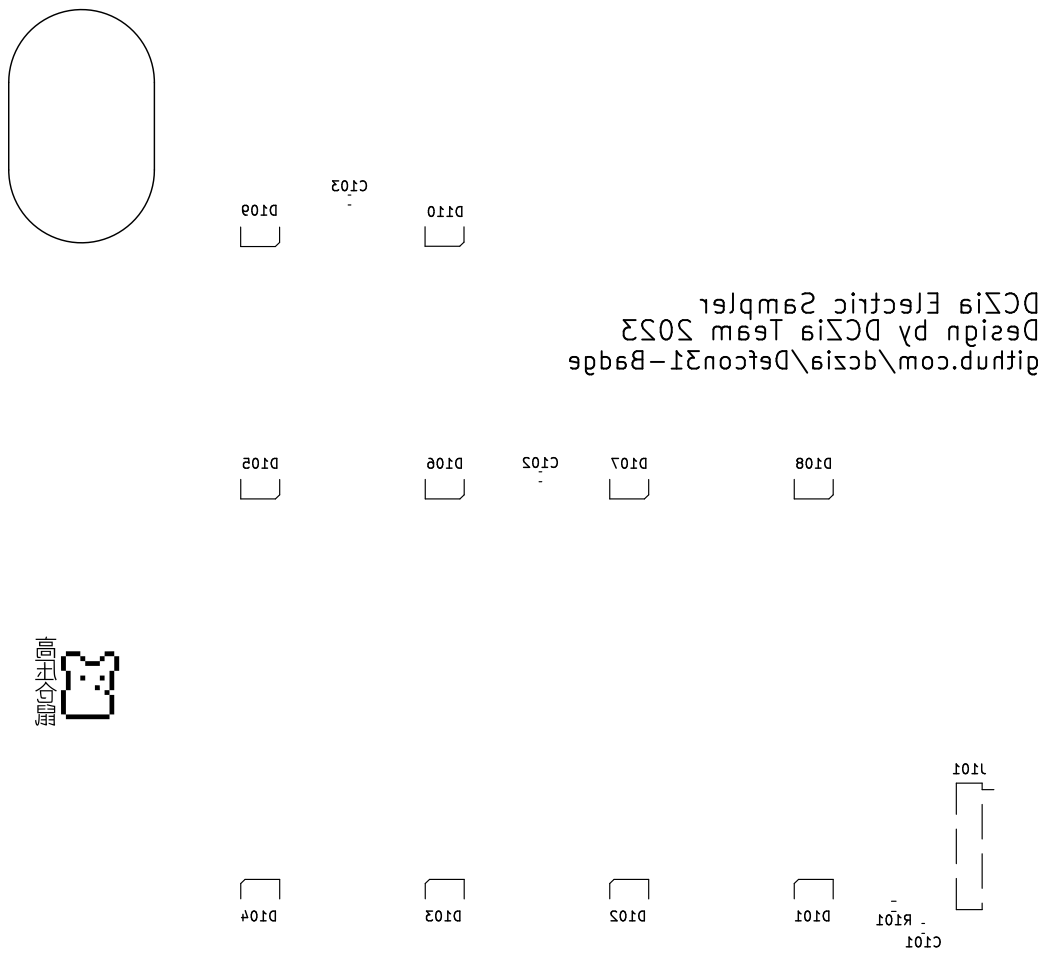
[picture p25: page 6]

DCZia Electric Sampler
Design by DCZia Team 2023
github.com/dczia/Defcon31-Badge

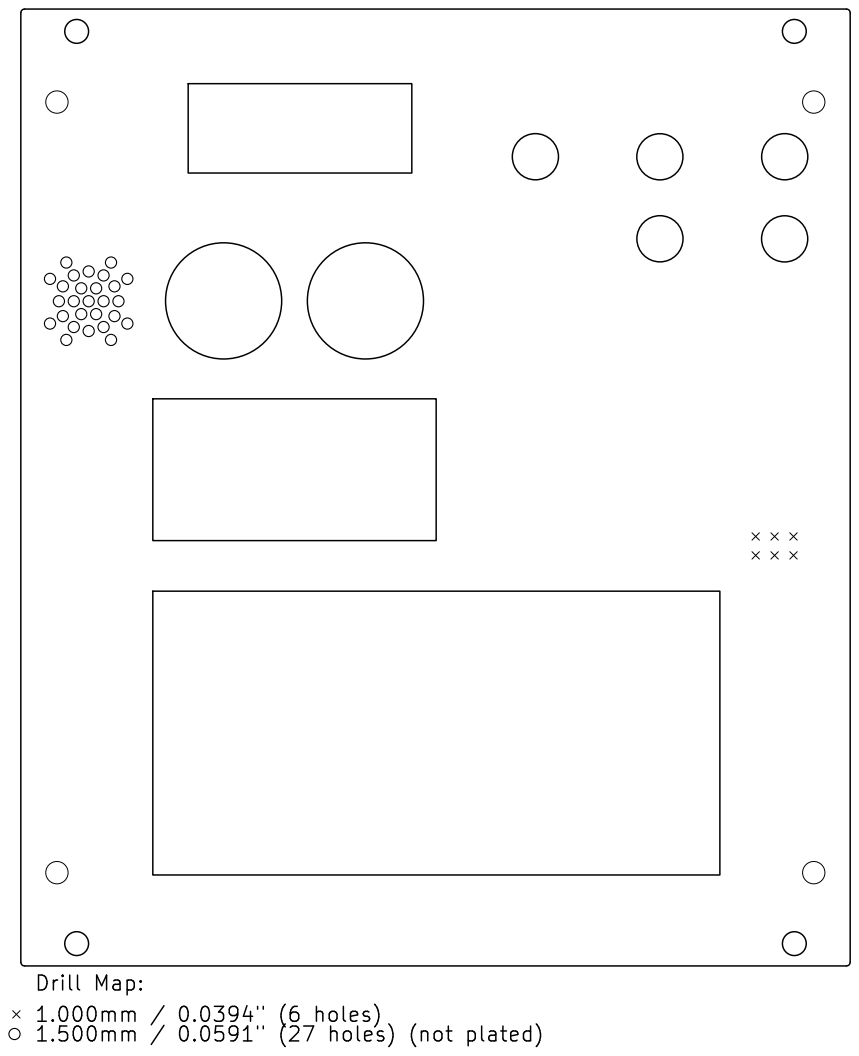
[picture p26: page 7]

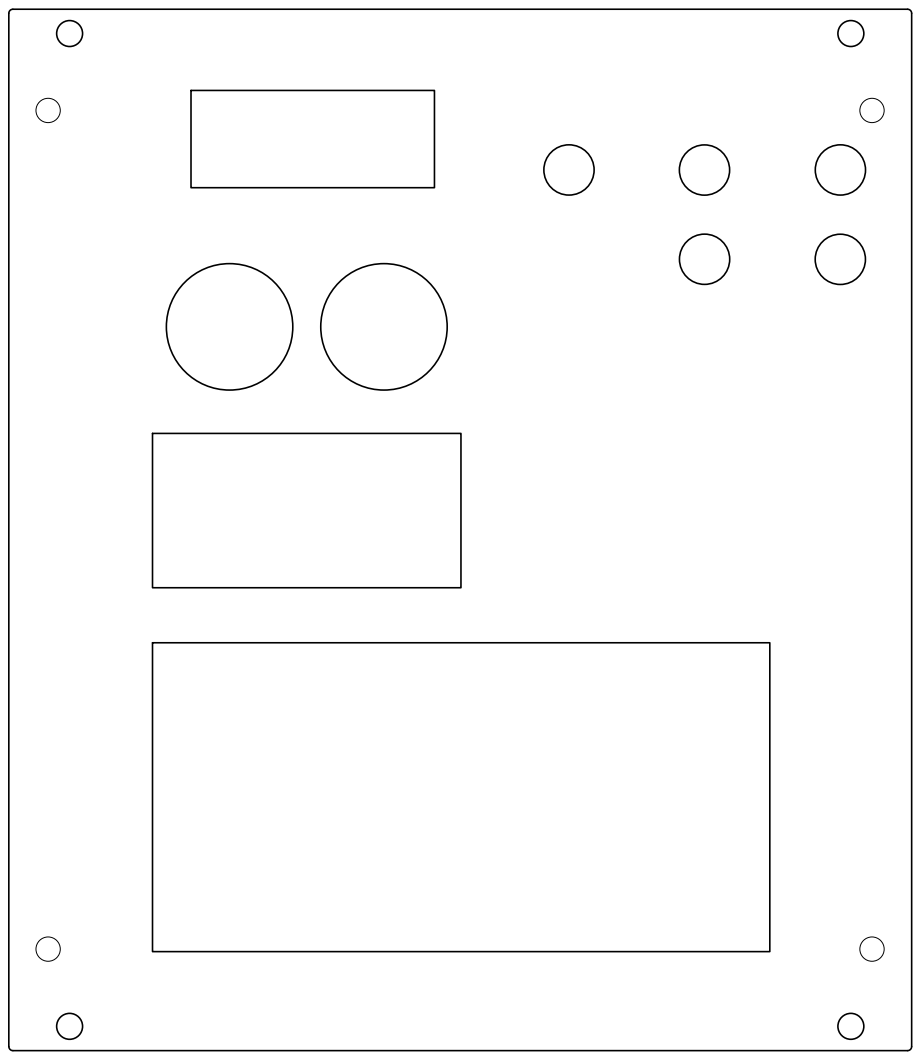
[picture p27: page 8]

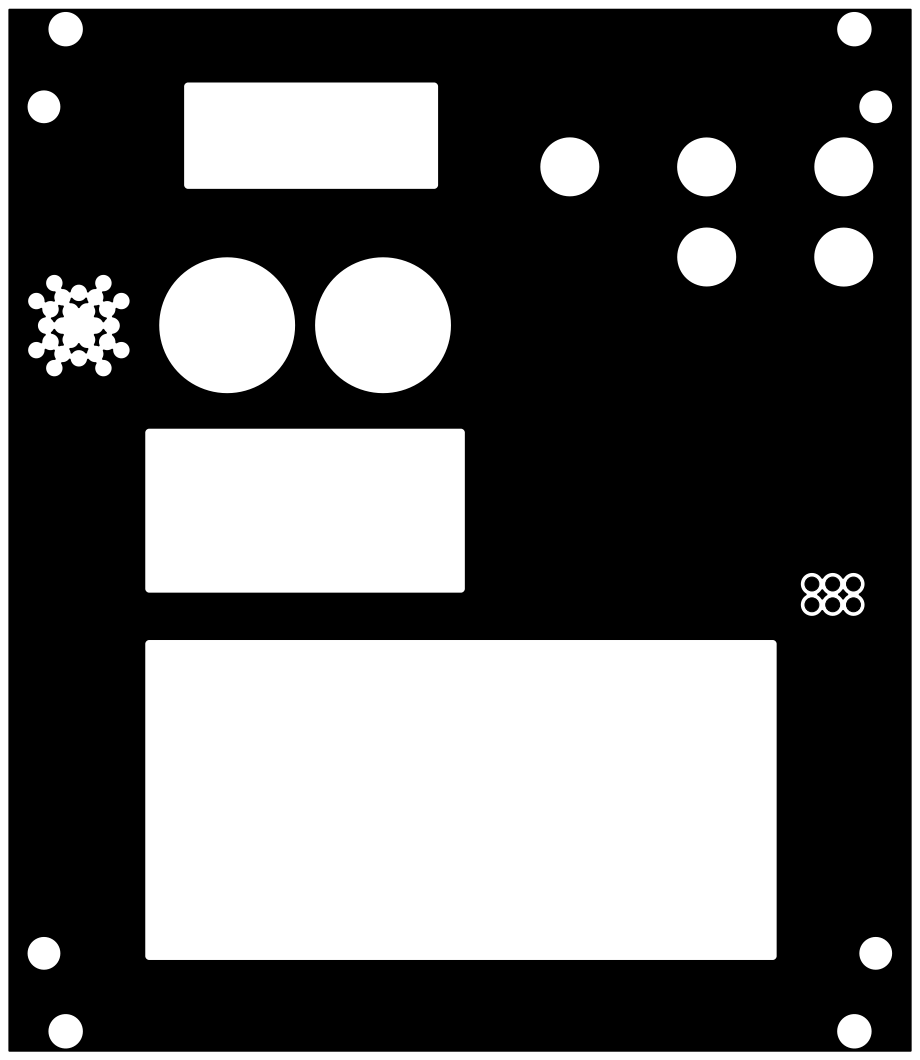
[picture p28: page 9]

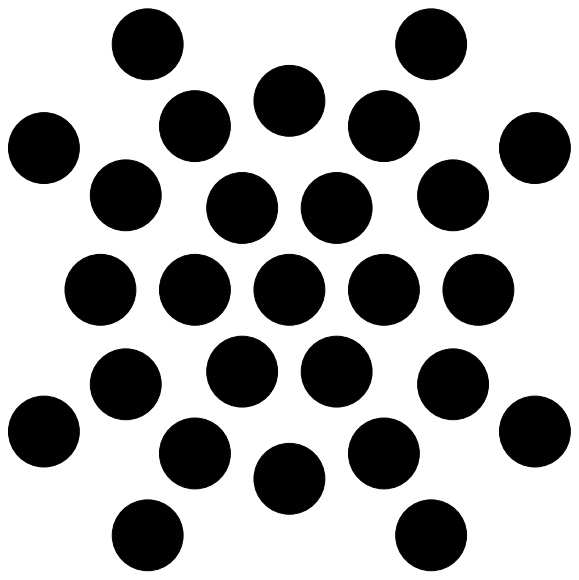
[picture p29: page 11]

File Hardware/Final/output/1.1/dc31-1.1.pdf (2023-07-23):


Id: 1/1 Title: DCZia Electric Sampler File: dc31-front.kicad_sch Sheet: / DCZia






DCZia Electric Sampler
Design by DCZia Team 2023
github.com/dczia/Defcon31-Badge





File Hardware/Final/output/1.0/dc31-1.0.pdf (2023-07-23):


File: dc31.kicad_sch Sheet: / DCZia @hamster

Id: 1/1 Title: DC31 Syth Badge





Design by DCZia Team 2023
github.com/dczia/Defcon31-Badge








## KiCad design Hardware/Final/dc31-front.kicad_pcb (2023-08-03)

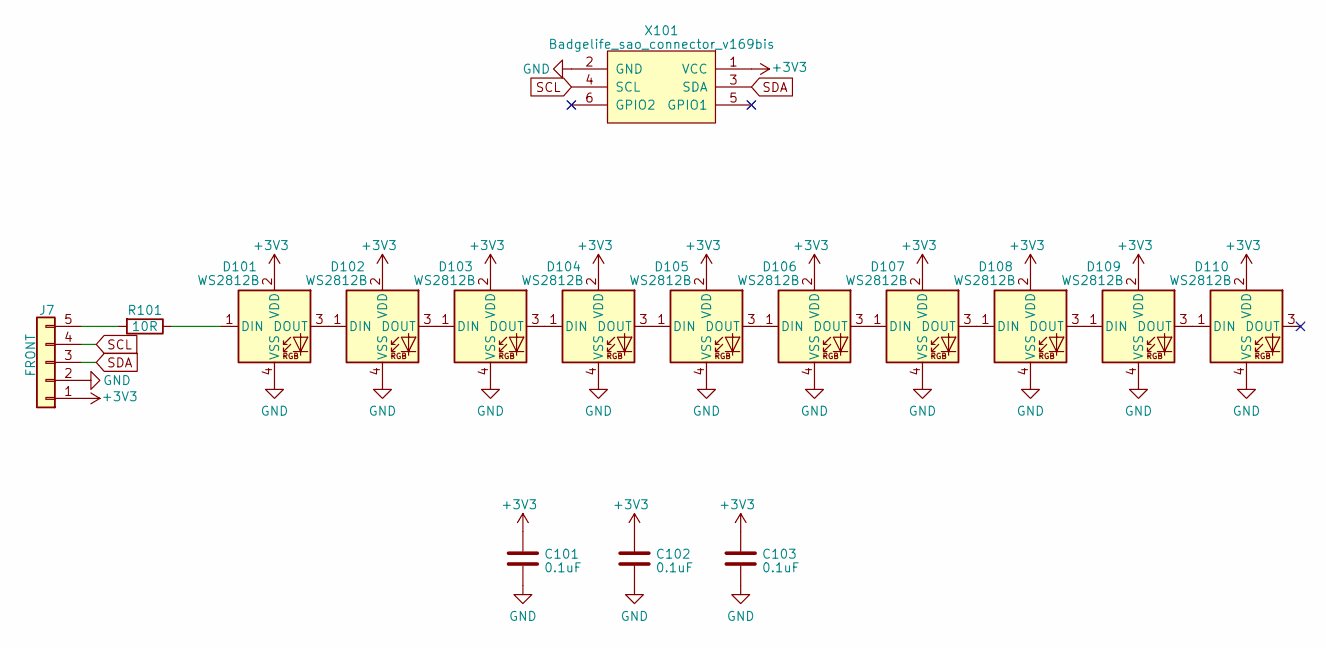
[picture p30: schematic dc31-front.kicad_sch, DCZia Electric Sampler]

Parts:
C101, C102, C103: 0.1uF; C_0603_1608Metric
D101, D102, D103, D104, D105, D106, D107, D108, D109, D110: WS2812B; LED_SK6812_4020_
J7: FRONT; PinSocket_1x05_P2.54mm_Vertical_SMD_Pin1Left
R101: 10R; R_0603_1608Metric
X101: Badgelife_sao_connector_v169bis; Badgelife-Shitty-v1.69bis

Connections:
+3V3: C101.1, C102.1, C103.1, D101.2 (VDD), D102.2 (VDD), D103.2 (VDD), D104.2 (VDD), D105.2 (VDD), D106.2 (VDD), D107.2 (VDD), D108.2 (VDD), D109.2 (VDD), D110.2 (VDD), X101.1 (VCC); also elsewhere on the board
GND: C101.2, C102.2, C103.2, D101.4 (VSS), D102.4 (VSS), D103.4 (VSS), D104.4 (VSS), D105.4 (VSS), D106.4 (VSS), D107.4 (VSS), D108.4 (VSS), D109.4 (VSS), D110.4 (VSS), X101.2 (GND); also elsewhere on the board
unnamed: D101.1 (DIN), R101.1
unnamed: D101.3 (DOUT), D102.1 (DIN)
unnamed: D102.3 (DOUT), D103.1 (DIN)
unnamed: D103.3 (DOUT), D104.1 (DIN)
unnamed: D104.3 (DOUT), D105.1 (DIN)
unnamed: D105.3 (DOUT), D106.1 (DIN)
unnamed: D106.3 (DOUT), D107.1 (DIN)
unnamed: D107.3 (DOUT), D108.1 (DIN)
unnamed: D108.3 (DOUT), D109.1 (DIN)
unnamed: D109.3 (DOUT), D110.1 (DIN)
unnamed 12: R101.2; also elsewhere on the board
SCL: X101.4 (SCL); also elsewhere on the board
SDA: X101.3 (SDA); also elsewhere on the board

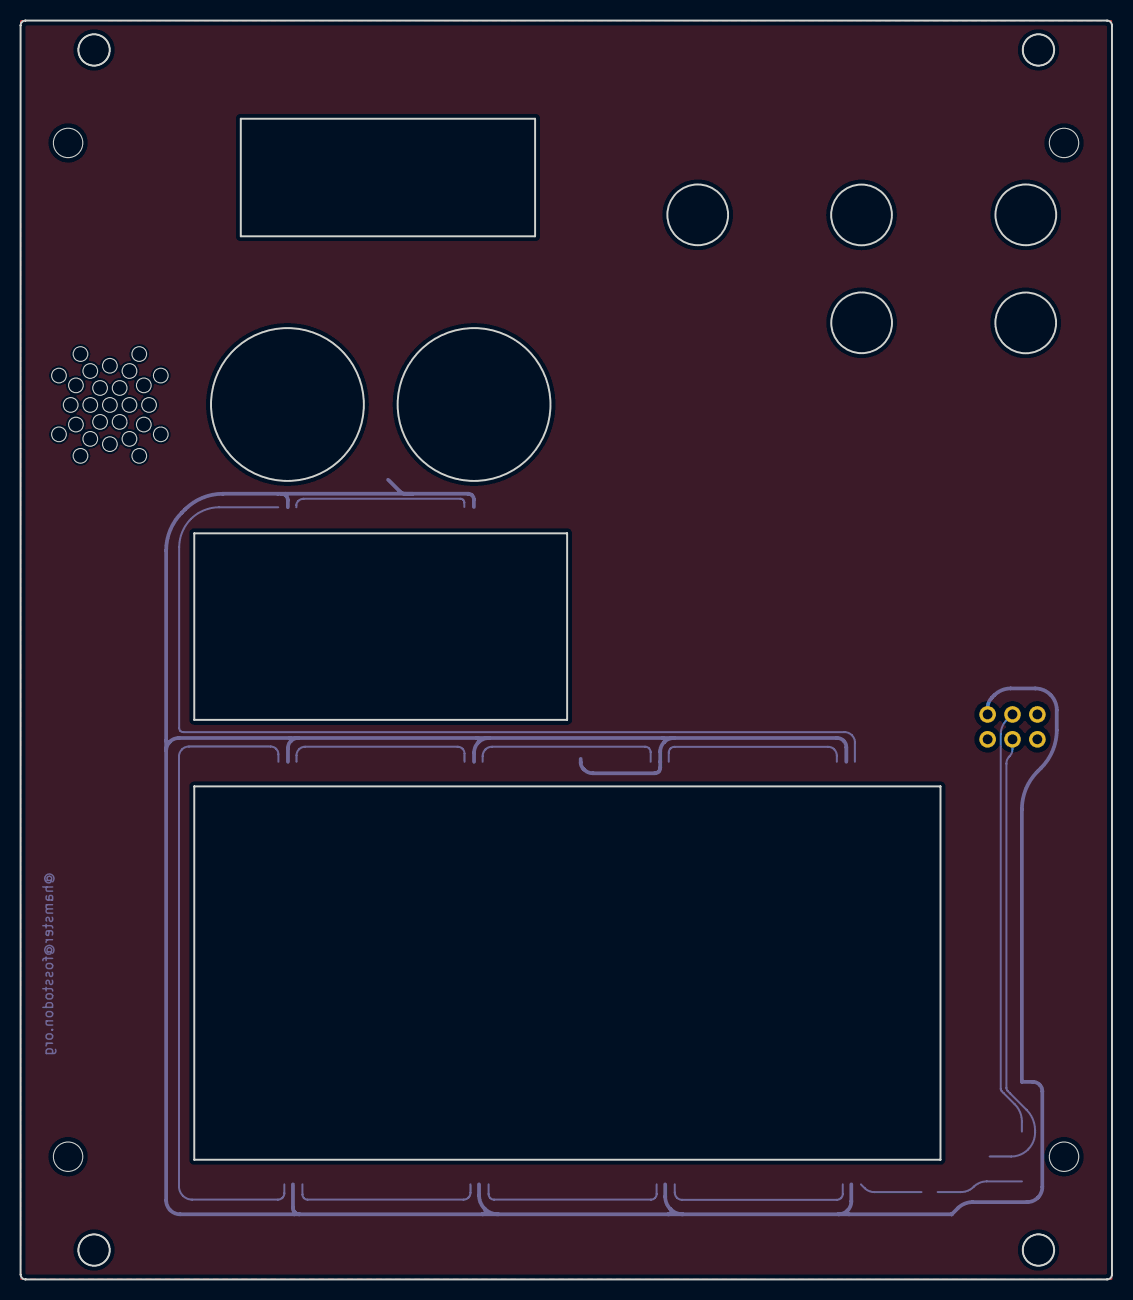
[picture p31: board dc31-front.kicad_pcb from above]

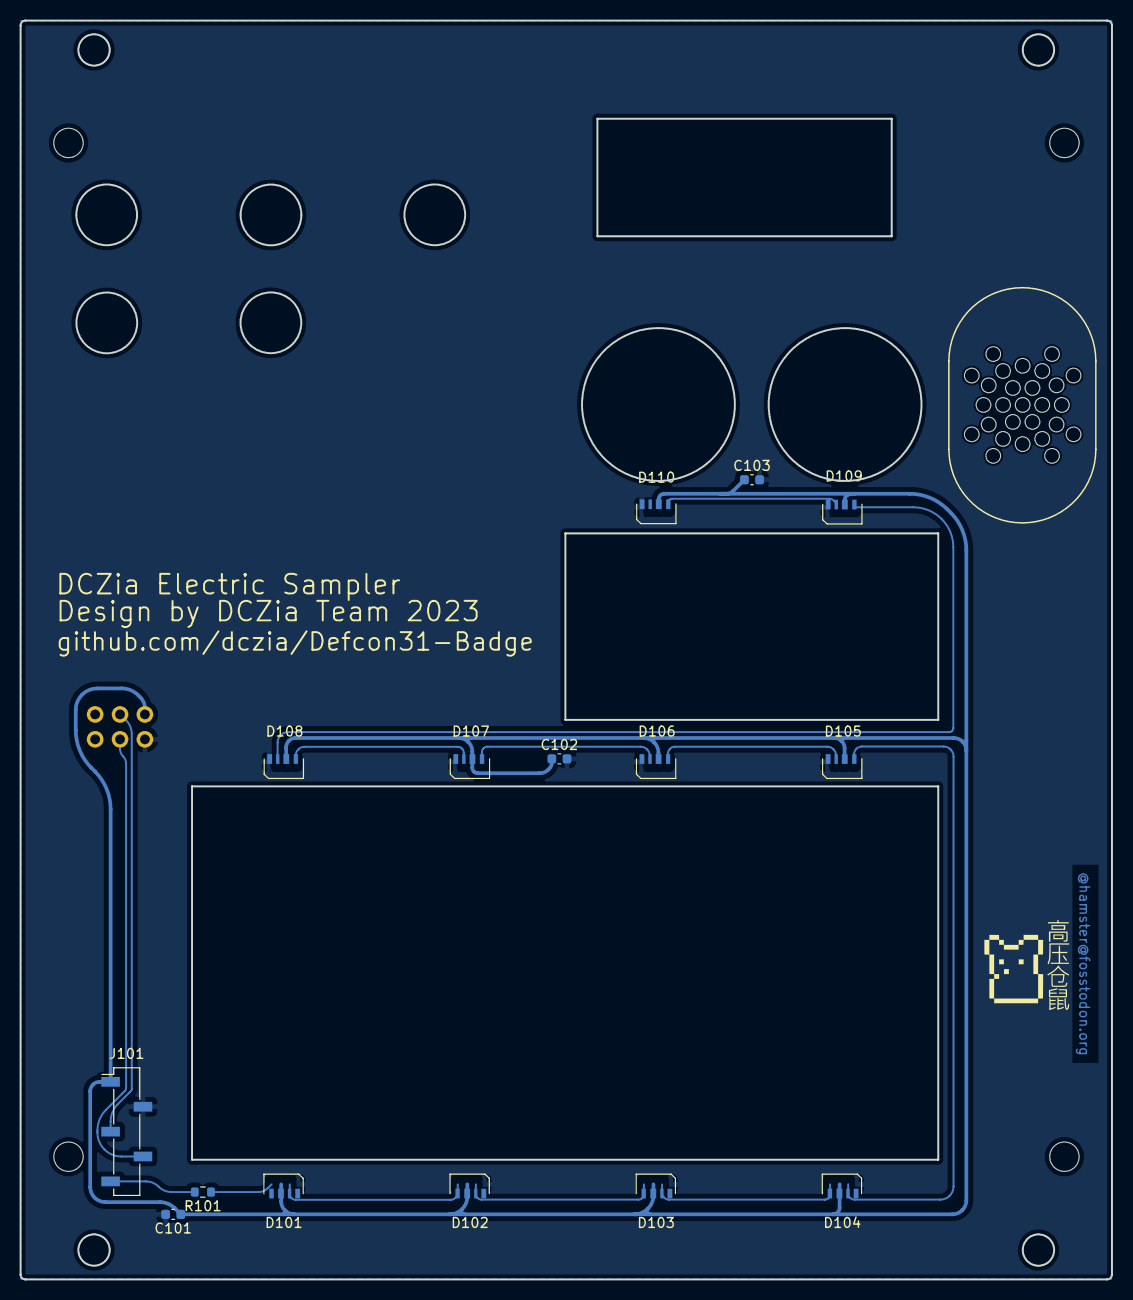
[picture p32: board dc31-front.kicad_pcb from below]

Board: 2 copper layers, 111.4 x 128.5 mm, 20 parts (15 on the bottom side), 15 nets.

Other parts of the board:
HOLE1, HOLE2, HOLE3, HOLE4: MountingHole_1.6
J101: FRONT; PinSocket_1x05_P2.54mm_Vertical_SMD_Pin1Left

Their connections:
+3V3: J101.1; also elsewhere on the board
GND: J101.2; also elsewhere on the board
unnamed 12: J101.5; also elsewhere on the board
SCL: J101.4; also elsewhere on the board
SDA: J101.3; also elsewhere on the board

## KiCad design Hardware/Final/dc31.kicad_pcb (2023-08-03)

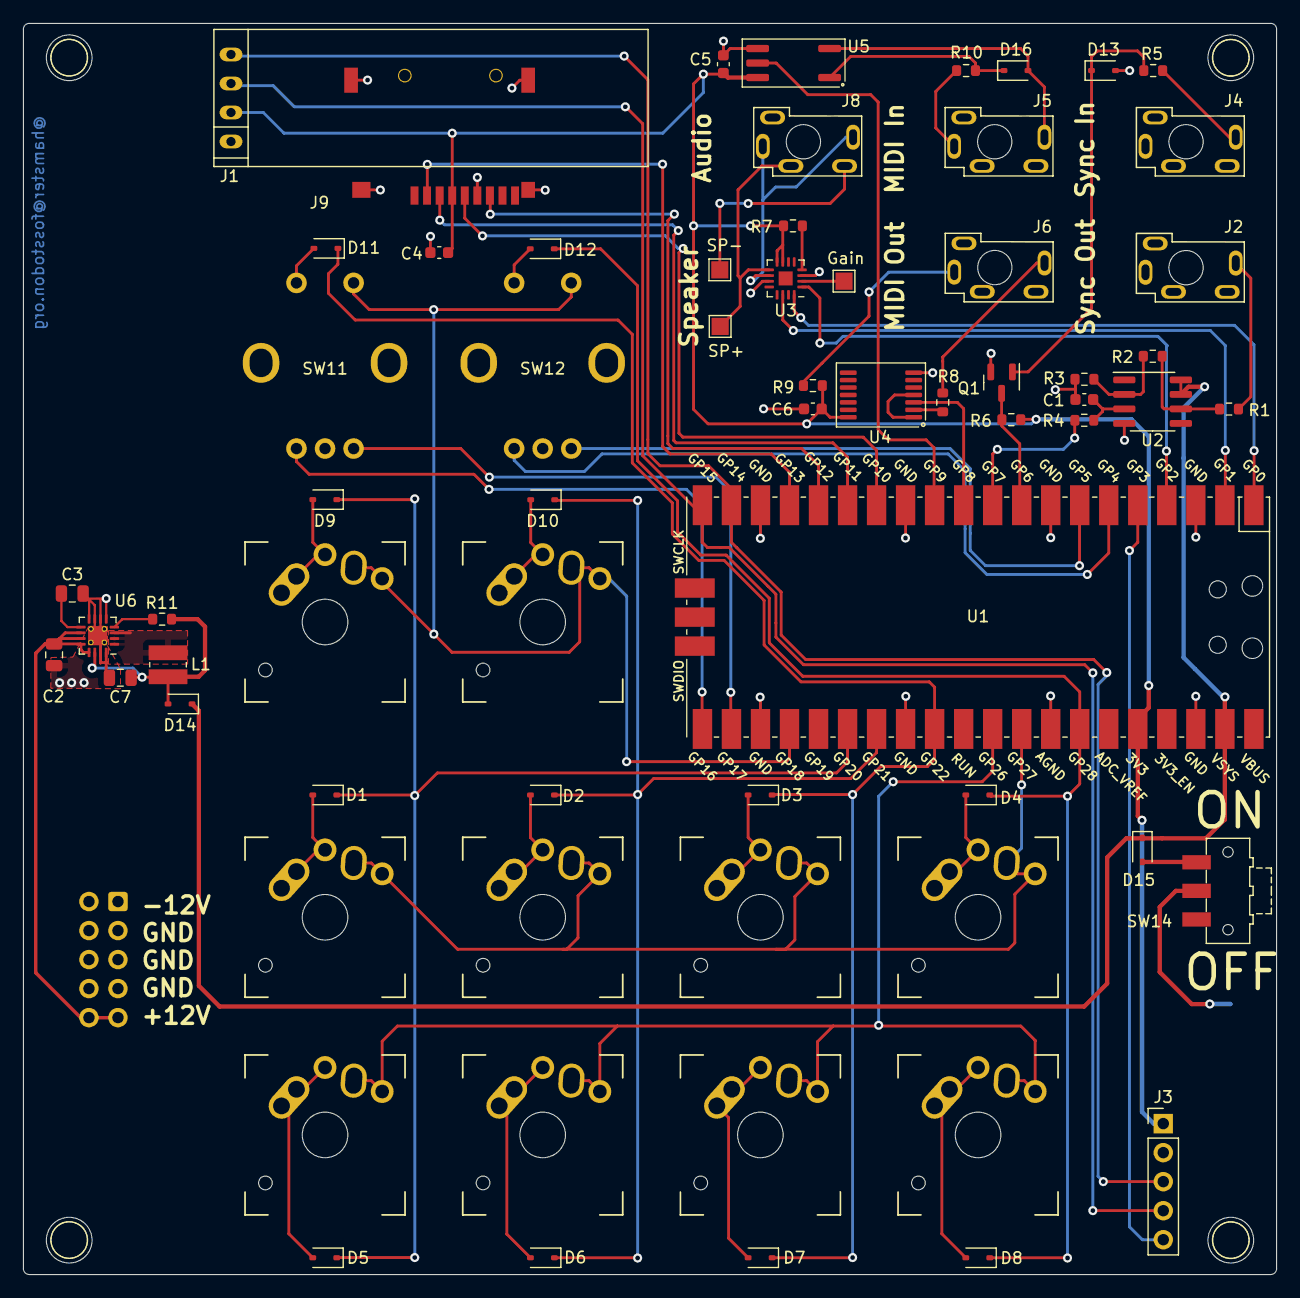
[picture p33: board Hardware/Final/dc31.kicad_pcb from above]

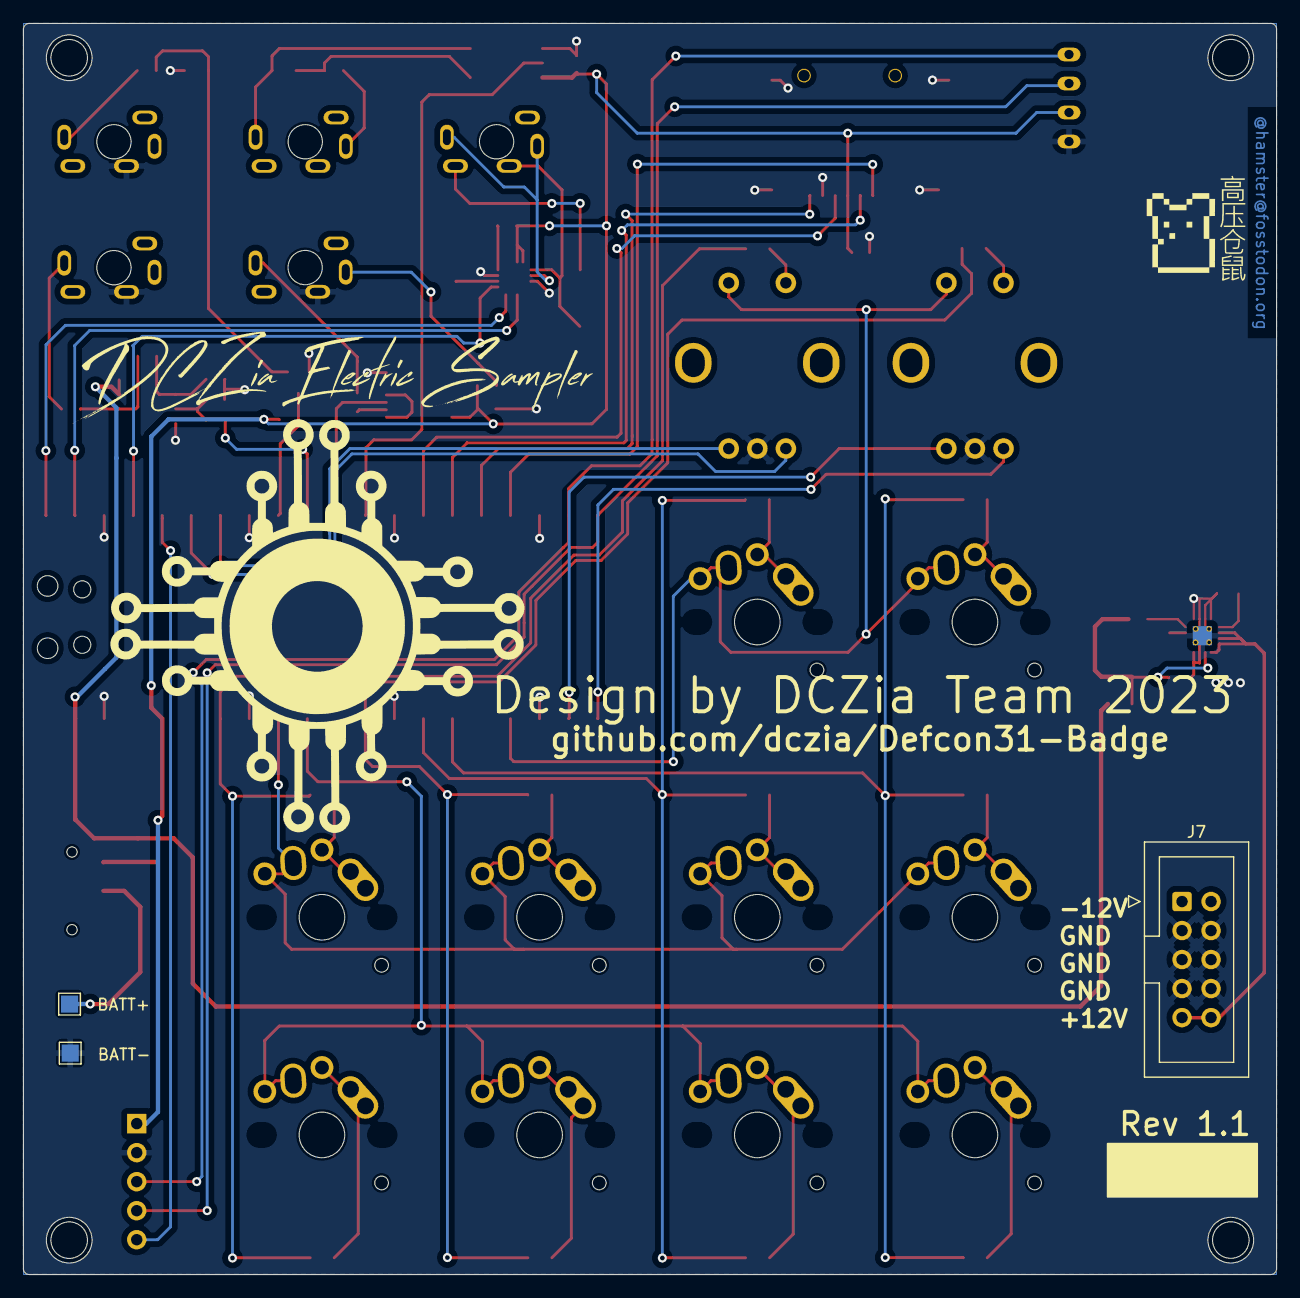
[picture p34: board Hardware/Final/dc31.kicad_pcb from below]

Board: 2 copper layers, 109.7 x 109.5 mm, 73 parts (3 on the bottom side), 65 nets.

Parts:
C1, C4, C5, C6: 0.1uF; C_0603_1608Metric
C2: 10uF; C_0805_2012Metric
C3: 3.3nF; C_0805_2012Metric
C7: 22uF; C_0805_2012Metric
D1, D2, D3, D4, D5, D6, D7, D8, D9, D10, D11, D12, D13, D16: D_Small_Filled; D_SOD-323
D14, D15: D_Schottky; D_SOD-323
HOLE1, HOLE2, HOLE3, HOLE4: MountingHole_1.6
J1: OLED
J2: SYNC OUT; STX-3790-5N
J3: FRONT; PinHeader_1x05_P2.54mm_Vertical
J4: SYNC IN; STX-3790-5N
J5: MIDI IN; STX-3790-5N
J6: MIDI OUT; STX-3790-5N
J7: Eurorack; IDC-Header_2x05_P2.54mm_Vertical
J8: HEADPHONE; STX-3790-5N
J9: Micro_SD_Card_SPI; MicroSD-Socket-Seeed-320090008
L1: 2.2uH; L_Wuerth_MAPI-3015
Q1: 3904; SOT-23
R1, R4: 1k; R_0603_1608Metric
R2: 220k; R_0603_1608Metric
R3, R5, R11: 100k; R_0603_1608Metric
R6: 10k; R_0603_1608Metric
R7: 1M; R_0603_1608Metric
R8: 10R; R_0603_1608Metric
R9: 33R; R_0603_1608Metric
R10: 220R; R_0603_1608Metric
SW1: Seq1; MX-Alps-Choc-1U
SW2: Seq2; MX-Alps-Choc-1U
SW3: Seq3; MX-Alps-Choc-1U
SW4: Seq4; MX-Alps-Choc-1U
SW5: Seq5; MX-Alps-Choc-1U
SW6: Seq6; MX-Alps-Choc-1U
SW7: Seq7; MX-Alps-Choc-1U
SW8: Seq8; MX-Alps-Choc-1U
SW9: PlayPause; MX-Alps-Choc-1U
SW10: Function; MX-Alps-Choc-1U
SW11: Function Select; RotaryEncoder
SW12: Volume; RotaryEncoder
SW14: SW_SPDT; SW_SPDT_CK-JS102011SAQN
TP1: Gain; TestPoint_Pad_1.5x1.5mm
TP2: BATT+; TestPoint_Pad_1.5x1.5mm
TP3: BATT-; TestPoint_Pad_1.5x1.5mm
TP4: SP-; TestPoint_Pad_1.5x1.5mm
TP5: SP+; TestPoint_Pad_1.5x1.5mm
U1: Pico; RPi_Pico_SMD
U2: OPA341UA; SOIC-8_3.9x4.9mm_P1.27mm
U3: MAX98357A/B; TQFN-16-1EP_3x3mm_P0.5mm_EP1.23x1.23mm
U4: 74HC04; TSSOP-14_4.4x5mm_P0.65mm
U5: TLP2361; SO-5_4.4x3.6mm_P1.27mm
U6: TPS62153; VQFN-16-1EP_3x3mm_P0.5mm_EP1.68x1.68mm_ThermalVias

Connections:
+3V3: C4.2, C5.1, C6.1, J1.2, J3.1, J9.4 (VDD), R6.2, R7.1, R9.2, U1.36 (3V3), U3.7 (Vdd), U3.8 (Vdd), U4.14 (VCC), U5.6 (VCC)
+5V: C7.1, D14.2 (A), L1.2, R11.2, U6.14 (VOS)
+12V: C2.1, J7.9, J7.10, U6.10 (AVIN), U6.11 (PVIN), U6.12 (PVIN), U6.13 (EN)
C0: SW1.1, SW2.1, SW3.1, SW4.1, U1.32 (GPIO27_ADC1)
C1: SW5.1, SW6.1, SW7.1, SW8.1, U1.31 (GPIO26_ADC0)
C2: SW9.1, SW10.1, SW11.S2, SW12.S2, U1.24 (GPIO18)
ENC1_A: SW11.A, U1.21 (GPIO16)
ENC1_B: SW11.B, U1.22 (GPIO17)
ENC1_SW: D11.2 (A), SW11.S1
ENC2_A: SW12.A, U1.6 (GPIO4)
ENC2_B: SW12.B, U1.7 (GPIO5)
ENC2_SW: D12.2 (A), SW12.S1
GND: C1.2, C2.2, C3.2, C4.1, C5.2, C6.2, C7.2, D13.2 (A), J1.1, J2.5, J3.2, J4.5, J6.5, J7.3, J7.4, J7.5, J7.6, J7.7, J7.8, J9.6 (VSS), J9.10 (SHIELD), Q1.2 (E), R3.1, SW11.C, SW12.C, TP3.1, U1.3 (GND), U1.8 (GND), U1.13 (GND), U1.18 (GND), U1.23 (GND), U1.28 (GND), U1.33 (AGND), U1.38 (GND), U2.4 (V-), U3.3 (GND), U3.11 (GND), U4.7 (GND), U5.4 (GND), U6.5 (FB), U6.6 (AGND), U6.7 (FSW), U6.8 (DEF), U6.15 (PGND), U6.16 (PGND), U6.17 (EP)
I2S_BCLK: U1.1 (GPIO0), U3.16 (BCLK)
I2S_DIN: U1.4 (GPIO2), U3.1 (DIN)
I2S_LRCLK: U1.2 (GPIO1), U3.14 (LRCLK)
MIDI_IN: U1.12 (GPIO9), U5.5
MIDI_OUT: U1.11 (GPIO8), U4.3
unnamed: D1.2 (A), SW1.2
unnamed: D2.2 (A), SW2.2
unnamed: D3.2 (A), SW3.2
unnamed: D4.2 (A), SW4.2
unnamed: D5.2 (A), SW5.2
unnamed: D6.2 (A), SW6.2
unnamed: D7.2 (A), SW7.2
unnamed: D8.2 (A), SW8.2
unnamed: D9.2 (A), SW9.2
unnamed: D10.2 (A), SW10.2
unnamed: D13.1 (K), Q1.1 (B), R5.2
unnamed: D15.2 (A), SW14.3 (C)
unnamed: D16.2 (A), J5.4, U5.3
unnamed: D16.1 (K), R10.2, U5.1
unnamed: J2.4, R1.1
unnamed: J4.4, R5.1
unnamed: J5.1, R10.1
unnamed: J6.1, R9.1
unnamed: J6.4, R8.1
unnamed: J8.3, TP5.1
unnamed: L1.1, U6.1 (SW), U6.2 (SW), U6.3 (SW)
unnamed: R1.2, R2.1, U2.6
unnamed: R8.2, U4.2
unnamed: SW14.2 (B), TP2.1
unnamed: C1.1, R4.1, U2.3 (+)
unnamed: R2.2, R3.2, U2.2 (-)
unnamed: TP1.1, U3.2 (GAIN_SLOT)
unnamed: J8.1, J8.4, U3.10 (OUTN)
unnamed: J8.5, TP4.1, U3.9 (OUTP)
unnamed: R7.2, U3.4 (~SD_MODE)
unnamed: U4.1, U4.4
unnamed: R11.1, U6.4 (PG)
unnamed: C3.1, U6.9 (SS/TR)
R0: D1.1 (K), D5.1 (K), D9.1 (K), U1.26 (GPIO20)
R1: D2.1 (K), D6.1 (K), D10.1 (K), U1.27 (GPIO21)
R2: D3.1 (K), D7.1 (K), D11.1 (K), U1.29 (GPIO22)
R3: D4.1 (K), D8.1 (K), D12.1 (K), U1.34 (GPIO28_ADC2)
RGB: J3.5, U1.5 (GPIO3)
SCL: J1.3, J3.4, U1.20 (GPIO15)
SDA: J1.4, J3.3, U1.19 (GPIO14)
SD_CS: J9.2 (/CS), U1.17 (GPIO13)
SD_MISO: J9.7 (DO), U1.16 (GPIO12)
SD_MOSI: J9.3 (DI), U1.15 (GPIO11)
SD_SCK: J9.5 (CLK), U1.14 (GPIO10)
SYNC_IN: Q1.3 (C), R6.1, U1.9 (GPIO6)
SYNC_OUT: R4.2, U1.10 (GPIO7)
VCC: D14.1 (K), D15.1 (K), U1.39 (VSYS), U2.7 (V+), U2.8 (~SHDN)

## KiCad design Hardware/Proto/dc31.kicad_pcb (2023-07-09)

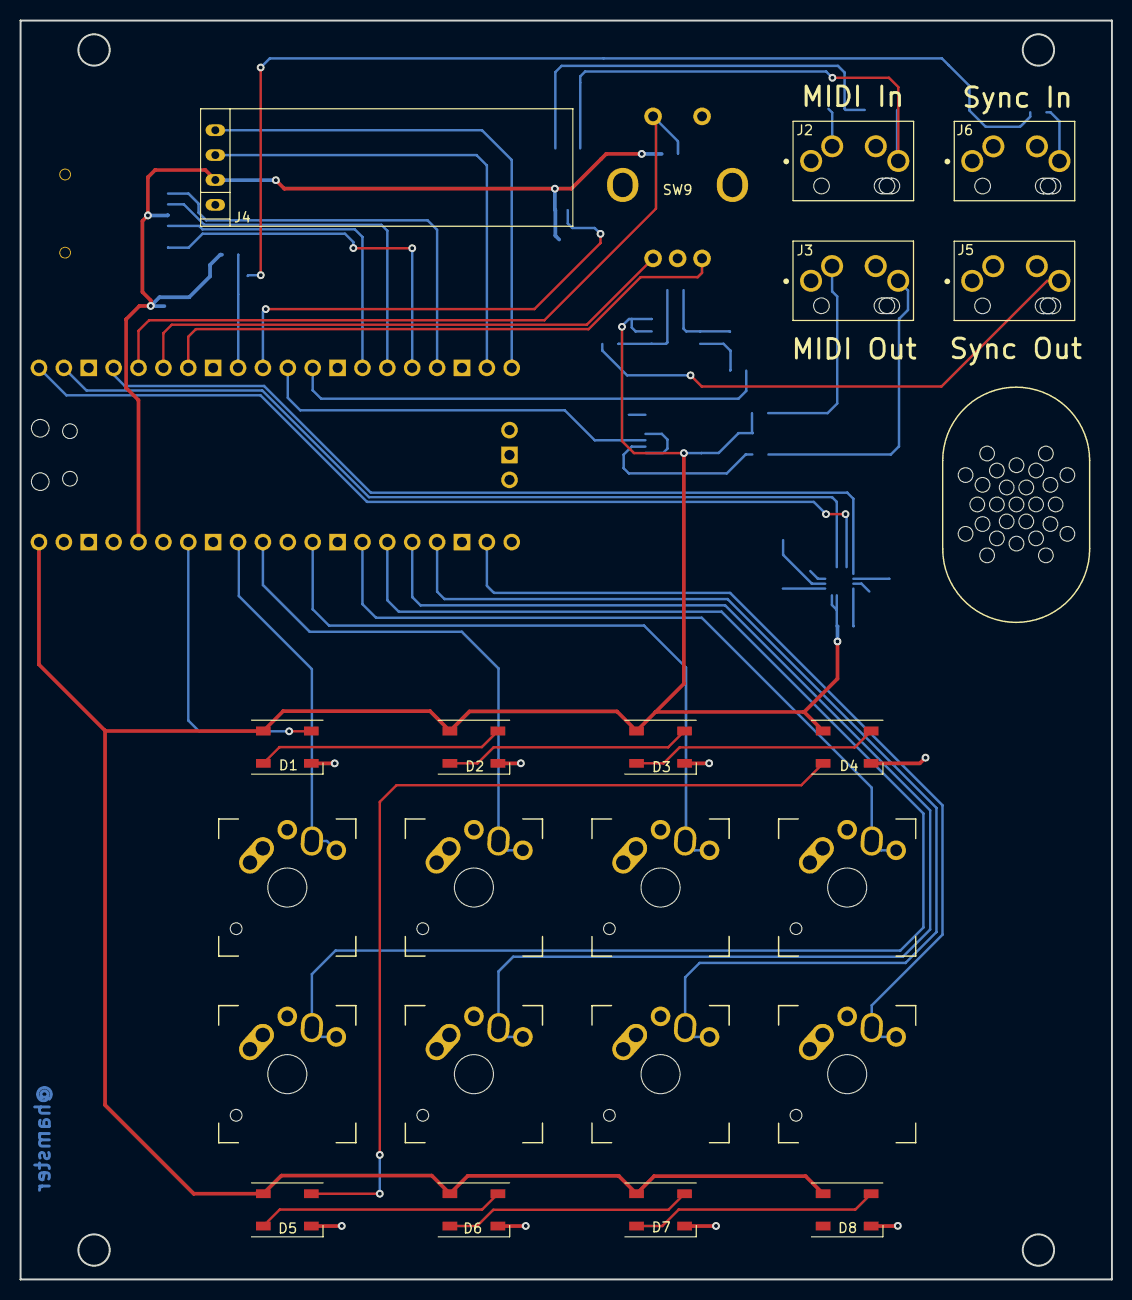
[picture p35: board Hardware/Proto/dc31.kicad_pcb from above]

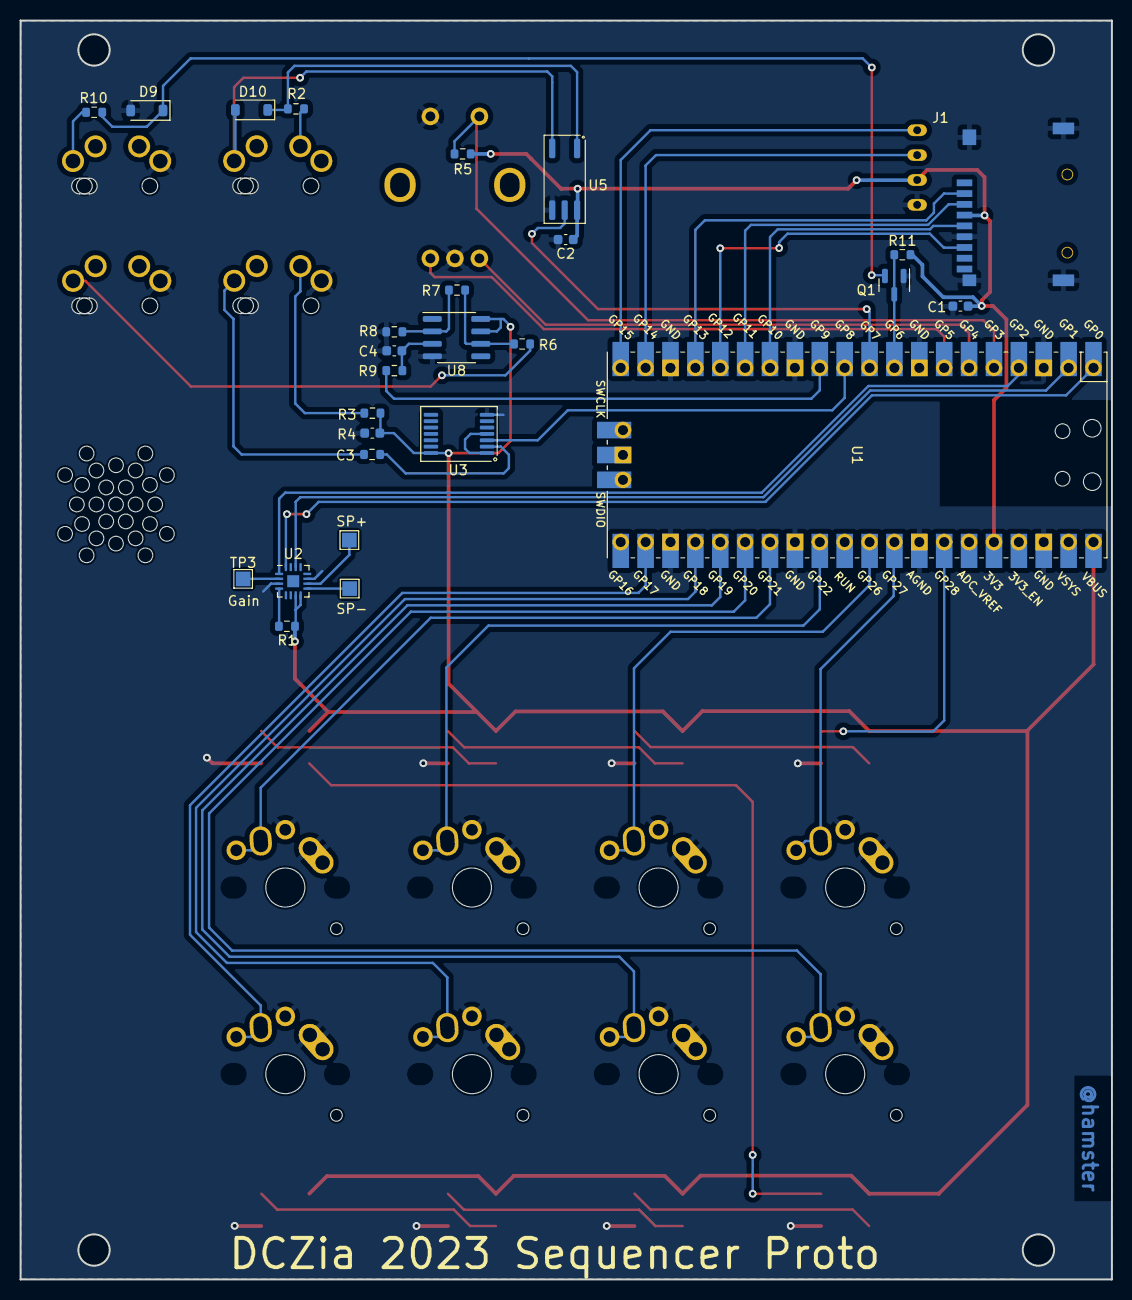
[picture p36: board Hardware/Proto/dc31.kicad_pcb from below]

Board: 2 copper layers, 111.4 x 128.5 mm, 49 parts (27 on the bottom side), 52 nets.

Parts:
C1, C2, C3, C4: 0.1uF; C_0603_1608Metric
D1, D2, D3, D4, D5, D6, D7, D8: WS2812B; LED_WS2812B_PLCC4_5.0x5.0mm_P3.2mm
D9, D10: D_Small_Filled; D_SOD-123
J1: Micro_SD_Card_SPI; MicroSD-Socket-Seeed-320090008
J2: MIDI IN; MOLEX_47257-0001
J3: MIDI OUT; MOLEX_47257-0001
J4: OLED
J5: SYNC OUT; MOLEX_47257-0001
J6: SYNC IN; MOLEX_47257-0001
Q1: 3904; SOT-23
R1: 1M; R_0603_1608Metric
R2, R3, R4: 220R; R_0603_1608Metric
R5, R11: 10k; R_0603_1608Metric
R6, R9: 1k; R_0603_1608Metric
R7: 220k; R_0603_1608Metric
R8, R10: 100k; R_0603_1608Metric
SW1, SW2, SW3, SW4, SW5, SW6, SW7, SW8: SW_Push; MX-Alps-Choc-1U
SW9: Rotary; RotaryEncoder
TP1: SP+; TestPoint_Pad_1.5x1.5mm
TP2: SP-; TestPoint_Pad_1.5x1.5mm
TP3: Gain; TestPoint_Pad_1.5x1.5mm
U1: Pico; RPi_Pico_SMD_TH
U2: MAX98357A/B; TQFN-16-1EP_3x3mm_P0.5mm_EP1.23x1.23mm
U3: 74HC04; TSSOP-14_4.4x5mm_P0.65mm
U5: TLP2361; SO-5_4.4x3.6mm_P1.27mm
U8: OPA341UA; SOIC-8_3.9x4.9mm_P1.27mm

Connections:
+3V3: C1.2, C2.1, J1.4 (VDD), J4.2, R5.1, R11.2, U1.36 (3V3), U5.6 (VCC)
ENC1_A: SW9.A, U1.6 (GPIO4)
ENC1_B: SW9.B, U1.7 (GPIO5)
ENC1_SW: R5.2, SW9.S1, U1.5 (GPIO3)
GND: C1.1, C2.2, C3.2, C4.2, D1.3 (VSS), D2.3 (VSS), D3.3 (VSS), D4.3 (VSS), D5.3 (VSS), D6.3 (VSS), D7.3 (VSS), D8.3 (VSS), D9.2 (A), J1.6 (VSS), J1.10 (SHIELD), J3.1, J4.1, J5.1, J6.1, Q1.1 (E), R8.1, SW1.2, SW2.2, SW3.2, SW4.2, SW5.2, SW6.2, SW7.2, SW8.2, SW9.C, SW9.S2, U1.3 (GND), U1.8 (GND), U1.13 (GND), U1.18 (GND), U1.23 (GND), U1.28 (GND), U1.33 (AGND), U1.38 (GND), U2.3 (GND), U2.11 (GND), U3.7 (GND), U5.4 (GND), U8.4 (V-)
I2S_BCLK: U1.1 (GPIO0), U2.16 (BCLK)
I2S_DIN: U1.4 (GPIO2), U2.1 (DIN)
I2S_LRCLK: U1.2 (GPIO1), U2.14 (LRCLK)
MIDI_IN: U1.10 (GPIO7), U5.5
MIDI_OUT: U1.11 (GPIO8), U3.3
unnamed: D1.2 (DOUT), D2.4 (DIN)
unnamed: D2.2 (DOUT), D3.4 (DIN)
unnamed: D3.2 (DOUT), D4.4 (DIN)
unnamed: D4.2 (DOUT), D5.4 (DIN)
unnamed: D5.2 (DOUT), D6.4 (DIN)
unnamed: D6.2 (DOUT), D7.4 (DIN)
unnamed: D7.2 (DOUT), D8.4 (DIN)
unnamed: D9.1 (K), Q1.2 (B), R10.2
unnamed: D10.2 (A), J2.2, U5.3
unnamed: D10.1 (K), R2.2, U5.1
unnamed: J2.3, R2.1
unnamed: J3.2, R4.1
unnamed: J3.3, R3.1
unnamed: J5.2, R6.1
unnamed: J6.2, R10.1
unnamed: R4.2, U3.2
unnamed: R6.2, R7.1, U8.6
unnamed: TP3.1, U2.2 (GAIN_SLOT)
unnamed: TP2.1, U2.10 (OUTN)
unnamed: TP1.1, U2.9 (OUTP)
unnamed: R1.2, U2.4 (~SD_MODE)
unnamed: U3.1, U3.4
unnamed: C4.1, R9.1, U8.3 (+)
unnamed: R7.2, R8.2, U8.2 (-)
RGB_IN: D1.4 (DIN), U1.34 (GPIO28_ADC2)
SCL: J4.3, U1.19 (GPIO14)
SDA: J4.4, U1.20 (GPIO15)
SD_CS: J1.2 (/CS), U1.17 (GPIO13)
SD_MISO: J1.7 (DO), U1.16 (GPIO12)
SD_MOSI: J1.3 (DI), U1.15 (GPIO11)
SD_SCK: J1.5 (CLK), U1.14 (GPIO10)
SW1: SW1.1, U1.32 (GPIO27_ADC1)
SW2: SW2.1, U1.31 (GPIO26_ADC0)
SW3: SW3.1, U1.29 (GPIO22)
SW4: SW4.1, U1.27 (GPIO21)
SW5: SW5.1, U1.26 (GPIO20)
SW6: SW6.1, U1.25 (GPIO19)
SW7: SW7.1, U1.24 (GPIO18)
SW8: SW8.1, U1.22 (GPIO17)
SYNC_IN: Q1.3 (C), R11.1, U1.9 (GPIO6)
SYNC_OUT: R9.2, U1.12 (GPIO9)
VBUS: C3.1, D1.1 (VDD), D2.1 (VDD), D3.1 (VDD), D4.1 (VDD), D5.1 (VDD), D6.1 (VDD), D7.1 (VDD), D8.1 (VDD), R1.1, R3.2, U1.40 (VBUS), U2.7 (Vdd), U2.8 (Vdd), U3.14 (VCC), U8.7 (V+), U8.8 (~SHDN)

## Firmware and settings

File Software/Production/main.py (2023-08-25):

import time

from setup import (
    select_enc,
    volume_enc,
)

# from audiocore import WaveFile
from StartupState import StartupState
from FlashyState import FlashyState
from MIDIState import MIDIState
from HIDState import HIDState
from MenuState import MenuState
from SequencerState import SamplerMenuState, SequencerMenuState, SequencerPlayState


class StateMachine(object):
    def __init__(self):
        self.state = None
        self.states = {}
        self.last_select_pos = select_enc.position
        self.last_volume_pos = volume_enc.position
        self.paused_state = None
        self.ticks_ms = 0
        self.animation = None
        self.last_state = None

    def add_state(self, state):
        self.states[state.name] = state

    def go_to_state(self, state_name):
        if self.state:
            self.state.exit(self)
            self.last_state = self.state.name
        self.state = self.states[state_name]
        self.state.enter(self)

    def update(self):
        if self.state:
            self.state.update(self)
            if self.ticks_ms > 0:
                time.sleep(self.ticks_ms / 1000)

    # When pausing, don't exit the state
    def pause(self):
        self.state = self.states["paused"]
        self.state.enter(self)

    # When resuming, don't re-enter the state
    def resume_state(self, state_name):
        if self.state:
            self.state.exit(self)
        self.state = self.states[state_name]


machine = StateMachine()
machine.add_state(StartupState())
machine.add_state(FlashyState())
machine.add_state(MIDIState())
machine.add_state(HIDState())
machine.add_state(MenuState())
machine.add_state(SamplerMenuState())
machine.add_state(SequencerMenuState())
machine.add_state(SequencerPlayState())
machine.go_to_state("startup")

while True:
    machine.update()

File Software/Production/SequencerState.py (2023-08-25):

import audiobusio
import audiomixer
import board
import terminalio
import time

from adafruit_display_text import label
from adafruit_led_animation.animation.rainbow import Rainbow
from audiocore import WaveFile
from MIDIState import send_note_on, send_note_off
from os import listdir
from supervisor import ticks_ms

from State import State
from utils import (
    selector_calcs,
    show_menu,
    neoindex,
)
from setup import (
    display,
    keys,
    neopixels,
    select_enc,
    volume_enc,
)


class file_sequences:
    files = []
    sequences = []
    # File sequencer class
    # Sets up a sequence track to play a .wav file sample at regular intervals
    # 8 step sequence tells whether to play

    def add_sequence(self, fname):
        self.files.append(fname)
        self.sequences.append(
            [
                [True, 0.5],
                [True, 0.5],
                [True, 0.5],
                [True, 0.5],
                [True, 0.5],
                [True, 0.5],
                [True, 0.5],
                [True, 0.5],
            ]
        )

    def show_sequence(self, sequence_index):
        for index, item in enumerate(self.sequences[sequence_index]):
            if item[0]:
                mapped_neopixel = neoindex(index)
                neopixels[mapped_neopixel] = (0, 0, 255)
                neopixels.show()
            elif item[0] is False:
                mapped_neopixel = neoindex(index)
                neopixels[mapped_neopixel] = (255, 0, 0)
                neopixels.show()


# MIDI sequencer class
# Sets up a sequence track to play MIDI messages at regular intervals
class midi_sequences:
    sequences = []

    def add_sequence(self):
        # Format [play, note, octave]
        self.sequences.append(
            [
                [True, 1, 2],
                [True, 3, 2],
                [True, 1, 2],
                [True, 5, 2],
                [True, 1, 2],
                [True, 3, 2],
                [True, 5, 2],
                [True, 3, 2],
            ]
        )

    def show_sequence(self):
        for index, item in enumerate(self.sequence):
            if item[0]:
                mapped_neopixel = neoindex(index)
                neopixels[mapped_neopixel] = (0, 0, 255)
                neopixels.show()
            elif item[0] is False:
                mapped_neopixel = neoindex(index)
                neopixels[mapped_neopixel] = (255, 0, 0)
                neopixels.show()


class SequencerMenuState:
    sequencer_mode = "midi"

    @property
    def name(self):
        return "sequencer_menu"

    def enter(self, machine):
        neopixels.fill((0, 0, 0))
        text = "MIDI Sequencer Menu"
        text_area = label.Label(terminalio.FONT, text=text, x=2, y=10)
        display.show(text_area)
        keys.events.clear()
        State.enter(self, machine)

    def play_midi(self):
        pass

    def exit(self, machine):
        neopixels.fill((255, 0, 0))
        self.color = (0, 0, 0)
        State.exit(self, machine)

    def update(self, machine):
        key_event = keys.events.get()
        if key_event and key_event.pressed:
            if key_event.key_number == 8:
                machine.go_to_state("sequencer_play")
            if key_event.key_number == 10:
                machine.go_to_state("menu")


class SamplerMenuState(State):
    sequencer_mode = "sampler"
    menu_items = [
        {
            "name": "add_sequence",
            "pretty": "Add Sequence",
        },
        {
            "name": "remove_sequence",
            "pretty": "Remove Sequence",
        },
        {
            "name": "edit_sequence",
            "pretty": "Edit Sequence",
        },
        {
            "name": "play_sequence",
            "pretty": "Play Sequence",
        },
        {
            "name": "exit",
            "pretty": "Exit",
        },
    ]

    @property
    def name(self):
        return "sampler_menu"

    def __init__(self):
        self.total_lines = 3
        self.list_length = len(self.menu_items)
        self.highlight = 1
        self.shift = 0
        # Get list of samples ONCE
        wav_files = []
        files = listdir("/samples/")
        for file in files:
            if file.endswith(".wav") and (not file.startswith(".")):
                wav_files.append({"name": file, "pretty": file})
        self.samples = wav_files

    def enter(self, machine):
        self.highlight = 1
        self.shift = 0
        self.last_position = 0
        if machine.animation is None:
            machine.animation = Rainbow(neopixels, speed=0.1)
        show_menu(self.menu_items, self.highlight, self.shift)
        State.enter(self, machine)

    def exit(self, machine):
        State.exit(self, machine)

    def select_wav(self):
        # Reset menu status
        self.highlight = 1
        self.shift = 0
        # Show valid files, select with encoder knob/button
        while True:
            if self.last_position != select_enc.position:
                (self.highlight, self.shift) = selector_calcs(
                    self.samples,
                    self.highlight,
                    self.shift,
                    self.last_position,
                    select_enc.position,
                )
                self.last_position = select_enc.position
            show_menu(self.samples, self.highlight, self.shift)
            key_event = keys.events.get()
            if key_event and key_event.pressed:
                selection = self.samples[self.highlight - 1 + self.shift]["name"]
                # Reset menu status
                self.highlight = 1
                self.shift = 0
                return selection

    def select_sequence(self, sequence_array):
        # Reset menu status
        self.highlight = 1
        self.shift = 0
        # Show valid sequences, select with encoder knob/button
        seq_select = []
        for index, seq in enumerate(sequence_array):
            seq_select.append({"name": f"{index}", "pretty": f"{index}: {seq}"})

        while True:
            if self.last_position != select_enc.position:
                (self.highlight, self.shift) = selector_calcs(
                    seq_select,
                    self.highlight,
                    self.shift,
                    self.last_position,
                    select_enc.position,
                )
                self.last_position = select_enc.position
            show_menu(seq_select, self.highlight, self.shift)
            key_event = keys.events.get()
            if key_event and key_event.pressed:

                selection = self.highlight - 1 + self.shift
                return selection
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

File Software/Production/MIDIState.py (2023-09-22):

import terminalio
from adafruit_midi.note_on import NoteOn
from adafruit_midi.note_off import NoteOff
from adafruit_midi.control_change import ControlChange
from adafruit_display_text import label
from State import State

from utils import (
    neoindex,
)
from setup import (
    display,
    keys,
    midi_serial,
    midi_usb,
    neopixels,
    select_enc,
    volume_enc,
)

c_1 = 24
d_1 = 26
e_1 = 28
f_1 = 29
g_1 = 31
a_1 = 33
b_1 = 35

# MIDI Functions
# def send_note_on(note, octv):
#     note = (note) + (12 * octv)
#     midi_serial.send(NoteOn(note, 120))
#     midi_usb.send(NoteOn(note, 120))


# def send_note_off(note, octv):
#     note = (note) + (12 * octv)
#     midi_serial.send(NoteOff(note, 0))
#     midi_usb.send(NoteOff(note, 120))

# MIDI Functions
def send_note_on(note):
    midi_serial.send(NoteOn(note, 120))
    midi_usb.send(NoteOn(note, 120))


def send_note_off(note):
    midi_serial.send(NoteOff(note, 0))
    midi_usb.send(NoteOff(note, 0))


def send_cc(number, val):
    midi_serial.send(ControlChange(number, val))
    midi_usb.send(ControlChange(number, val))


class MIDIState(State):
    @property
    def name(self):
        return "midi_controller"

    def enter(self, machine):
        text = "MIDI Controller"
        text_area = label.Label(terminalio.FONT, text=text, x=2, y=15)
        display.show(text_area)
        neopixels.fill((100, 100, 100))
        neopixels.show()
        # Reset encoder positions
        select_enc.position = 0
        volume_enc.position = 0
        self.last_select_position = select_enc.position
        self.last_volume_position = volume_enc.position
        self.notes = []  # Current pressed notes
        self.scale = []  # Current scale
        self.base = c_1  # Current base note
        self.current_scale = "major"
        self.generate_major_scale(self.base)
        keys.events.clear()
        State.enter(self, machine)

    def exit(self, machine):
        self.midi_panic()
        neopixels.fill((100, 100, 100))
        neopixels.show()
        State.exit(self, machine)

    def generate_major_scale(self, base):
        self.scale = []
        pattern = [0, 2, 4, 5, 7, 9, 11, 12]
        for value in pattern:
            self.scale.append(base + value)

    def generate_minor_scale(self, base):
        self.scale = []
        pattern = [0, 2, 3, 5, 7, 8, 10, 12]
        for value in pattern:
            self.scale.append(base + value)

    def midi_panic(self):
        send_cc(123, 0)  # Turn off all MIDI signal
        self.notes = []

    def base_down(self):
        if self.base > 24:
            self.base = self.base - 1

    def base_up(self):
        if self.base < 108:
            self.base = self.base + 1

    def octave_down(self):
        if self.scale[0] >= 36:
            for index, note in enumerate(self.scale):
                self.scale[index] = note - 12
            self.midi_panic()  # TODO improve tracking
            self.base = self.scale[0]

    def octave_up(self):
        if self.scale[0] <= 108:
            for index, note in enumerate(self.scale):
                self.scale[index] = note + 12
            self.midi_panic()  # TODO improve tracking
            self.base = self.scale[0]

    def poll_encoders(self):
        # Check select knob
        if select_enc.position != self.last_select_position:
            if select_enc.position < self.last_select_position:
                self.octave_down()
            if select_enc.position > self.last_select_position:
                self.octave_up()
            self.last_select_position = select_enc.position

        # Check volume knob
        if volume_enc.position != self.last_volume_position:
            # Change to minor if already major
            if self.current_scale == "major":
                self.generate_minor_scale(self.base)
                self.current_scale = "minor"
            # Change to major if already minor
            elif self.current_scale == "minor":
                self.generate_major_scale(self.base)
                self.current_scale = "major"
            self.last_volume_position = volume_enc.position

    def update(self, machine):
        # Listen on USB MIDI, resolves issues with some software
        # TODO Make this more elegant
        midi_usb.receive()
        key_event = keys.events.get()
        if key_event:
            if key_event.key_number < 8:
                if key_event.pressed:
                    key = key_event.key_number
                    note_value = self.scale[key]
                    self.notes.append(note_value)
                    send_note_on(note_value)
                    mapped_neopixel = neoindex(key)
                    neopixels[mapped_neopixel] = (255, 0, 0)
                if key_event.released:
                    key = key_event.key_number
                    note_value = self.scale[key]
                    if note_value in self.notes:
                        self.notes.remove(note_value)
                    send_note_off(note_value)
                    mapped_neopixel = neoindex(key)
                    neopixels[mapped_neopixel] = (100, 100, 100)
            elif (key_event.key_number == 8) and key_event.pressed:
                self.midi_panic()  # Play button kills all active MIDI notes
            elif (key_event.key_number == 9) and key_event.pressed:
                pass  # TODO Implement function key to shift function of encoder knobs
            elif (key_event.key_number == 10) and key_event.pressed:  # Select Button
                machine.go_to_state("menu")
                return
            elif (key_event.key_number == 11) and key_event.pressed:  # Volume Button
                print("TODO: Decide what the volume button does")

            neopixels.show()
        self.poll_encoders()

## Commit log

2023-07-09 Adding proto files to repo. This is As-Built proto.
    [47257-0001.step, DCZIA DC31 BADGE BOM.xlsx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]
2023-07-11 Adding test firmware Adding some 3d parts Some updates to the schematic as we prepare for final
    [12mm Incremental Encoder - BOURNS PEC11S - No Knob.STEP, 12mm Incremental Encoder - BOURNS PEC11S.stp, 47257-0001.step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]
2023-07-11 Update schematic and flesh out BOM with parts
    [DCZIA DC31 BADGE BOM.xlsx, dc31.kicad_sch, scratch.kicad_sch]
2023-07-14 Schematic is pretty much complete. Back board is 90% routed.
    [DCZIA DC31 BADGE BOM.xlsx, JS102011SAQN.SLDPRT, JS102011SAQN.stp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]
2023-07-15 State machine framework built. Basic I/O mostly implemented, and skeletons for most modes in place.
2023-07-15 Almost final, still need some artwork
    [Cherry MX Keycap.SLDPRT, Knob.SLDPRT, MX _ __.sldprt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]
2023-07-16 Adding SAO port to front panel Adding hamster art to boards A few more small tweaks before final export
    [dc31-front.kicad_pcb, dc31-front.kicad_sch, dc31.kicad_pcb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]
2023-07-19 Final files as submitted to fab
    [dc31-B_Cu.gbr, dc31-B_Fab.gbr, dc31-B_Mask.gbr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]
2023-07-23 Generated 1.1 rev to switch to KYCON 3.5mm jacks due to parts issues with the Molex
    [DCZIA DC31 BADGE BOM.xlsx, STX-3790-5N_rA5.STEP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]
2023-07-23 Update BOM
    [DCZIA DC31 BADGE BOM.xlsx]
2023-07-26 First cut at multi-track sampler, added new wav files (#25)
    Added rough cut of sequencer programming interface, some sequencer related led code
    Matching formatting
2023-07-27 First cut at multi-track sampler, added new wav files (#31)
    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
2023-07-28 Fix USB-HID bug (#32)
    When the badge is not plugged into a computer it doesn't start correctly
    because there is not USB host to create a virtual keyboard for
    [main.py]
2023-07-28 Sampler improvements (#38)
    * Improving sampler functionality
    * Improvements to menu states and flow
    ---------
2023-07-28 Sd exception (#39)
    * Add try/except for when an SD card is not loaded
    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
2023-08-03 Various hardware changes (#44)
    Updated some 3D models
    Updated BOM sheet
    Added bodge instructions
    Added some documentation
    [12mm Incremental Encoder Cap.stp.SLDPRT, 12mm Incremental Encoder Washer.stp.SLDPRT, COMPOUND-0.step.SLDPRT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]
2023-08-03 HID nitpick fixes (#43)
    - Handle more than one key event per update
    - Only call neopixels.show() once per update
    - Make keys number pad 1 through 8
    [main.py]
2023-08-03 Update Sampler and Flashy to scrolling menus (#47)
    * Update Sampler and Flashy to scrolling menus
    * Format with black
2023-08-03 Press encoder to skip intro (#49)
    [main.py]
2023-08-05 Fix MIDI error (#55)
    If a key is released when entering midi mode, an error occurs
    [MIDIState.py]
2023-08-05 Initial framework for production sequencer/sampler states (#56)
2023-08-09 Sampler bugfixes and slight menu improvements (definitely not panic coding) (#61)
    Sampler bugfixes and slight menu improvements
    Correction in neopixel mapping
    Added sampled (kick too low for speaker, but works on headphones)
    Changed default MIDI channel to 1
    [SequencerState.py, utils.py]
2023-08-09 Neopixel and menu fixes (#62)
    * Sampler bugfixes and slight menu improvements
    * Fixing LED indexing in MIDI controller and HID Controller
    Improving menu flow in sampler
    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
    [HIDState.py, MIDIState.py, SequencerState.py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]
2023-08-09 Sequence remove menu (#63)
    * Add remove sequence function in SamplerMenuState
    Supressed print statement in menu function
    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
    [SequencerState.py, utils.py]
2023-08-11 Lithobob manual samples (#65)
    * Added 909 Samples
    909 Samples from my RD-9 Drum machine. Processed in live
    * Update README.md
    * Updated Readme
2023-09-22 Bugfix for Resolume functionality (#70)
    [MIDIState.py, StartupState.py]
2026-10-27 Fix firmware crashes and resource leaks, add a regression test suite (#71)
    * Fix NeoPixel mapping for Play and Function keys
    neoindex() mapped key 8 (Play) and key 9 (Function) to NeoPixel indices
    10 and 11, but the front board carries exactly 10 addressable LEDs,
    D101-D110, so only indices 0-9 are valid.
    The try/except IndexError in neoindex() guards the mapping lookup, not
    the subsequent assignment, so the out-of-range index was returned to the
    caller intact. HIDState.update() gates on key_number < 10 and therefore
    passed keys 8 and 9 through, raising IndexError on neopixels[10] and
    dropping the badge to the REPL whenever Play or Function was pressed in
    USB HID mode. MIDIState escaped on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
